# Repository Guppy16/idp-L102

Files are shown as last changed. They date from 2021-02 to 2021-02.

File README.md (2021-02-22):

# IDP L102
Team Name: Root g \
Robots: pi, e

The ultimate repo for the idp

## Task
Design and simulate 2 similar robots with the same controller to collect coloured blocks in an arena.

## Assumptions

Sensor Modules:
- Colour sensor: 1 pixel camera; range of 1 - 10 cm
- Ultrasound sensor: Distance sensor; range = 20 - 140 cm; 3 cm resolution; 5% std
- IR sensor: Same as ultrasound
- Position sensor: GPS sensor; 1 cm accuracy; 3cm resolution
- Rotation sensor: Compass sensor; 5cm resolution

---
## Quick Links
- [Webots Tutorials](https://cyberbotics.com/doc/guide/tutorials)
- [Parts list](https://www.vle.cam.ac.uk/pluginfile.php/19716321/mod_resource/content/0/Tools%20and%20Parts%20List%20Rev%202.0.pdf)
- [CAD Model](https://drive.google.com/drive/folders/1H2YYnImyA4o20oNFYkEqHbo80u9imQ9U?usp=sharing)
- [G Drive Folder](https://drive.google.com/drive/folders/1ipIikCvn5a5h6eHkmM2m4k-qFC2ZiWPo)

---
## Schedule
- Week 1
  - Tue 26 14:30 - [First Presentation](https://docs.google.com/presentation/d/1Jz8pw5dtujUt2GG7nFzDspJj2hsbr5QpLF5pbWbA2lo)
- Week 2
  - Thurs 28 16:00 - [First Report](https://docs.google.com/presentation/d/1Jz8pw5dtujUt2GG7nFzDspJj2hsbr5QpLF5pbWbA2lo)
  - Tue 2 14:30 - [Progress Meeting 1](https://docs.google.com/presentation/d/1rXteifI9VppYjKGW0S_Uu-YhoCQ_Fu2L5HWq04Rq7eM)
- Week 3
  - Tue 9 14:30 - [Progress Meeting 2](https://docs.google.com/presentation/d/10YraGNGObi2IVQ-5OzObUJLeiZdhKT9rYpSfk6eRZUg)
- Week 4
  - Thurs 11 09:00 - First Competition
  - Tue 16 09:00 - [Final Presentation](https://docs.google.com/presentation/d/1EIgQiFh6fY0tn3hVZZiFkF7x_DoJgEBwd8sGT5k-Sp4)
  - Wed 17 14:00 - Final Competition
- Week 5
  - Mon 22 16:00 - Final Report and Documentation Deadline

## Plan
- [Gannt Chart](https://docs.google.com/spreadsheets/d/1-Yt5QpvAf2re6IKUbvELp7eMGsR5QatMflTM9JjYLDc)

- Before the first Presenetation ~ 5 days
  - [x] Gannt chart -> [ ] Make this better
  - [x] Get used to Webots ~ 2 days
  - [x] Initial CAD and PCB design ~ 5
  - [x] Inital algorithms for navigation ~ 4
- Before progress Meeting 1 ~ 7 days
  - [x] Complete simulation of environment (2 robots)
  - [x] Complete cad design of bulk components ~ 5
  - [x] Finished full schematic ~ 3
  - [x] Started implementing algorithms ~ 3
- Before Progress Meeting 2 ~ 7 days
  - [x] Finished CAD design
  - [x] Implemented Algorithms
  - [x] Start documentation
- Before First Competition ~ 2 days
  - [x] Fully tested algorithms in simulation
- Before Final Presentation
  - [x] Complete presentation ~ 
- Before Final Competition
  - [x] Improved the simulation environment
  - [x] Improved algorithms
- Before Final Report
  - [x] Mechanics Docs
  - [x] Electrical Docs
  - [x] Software Docs
  - [x] Cleanup README file

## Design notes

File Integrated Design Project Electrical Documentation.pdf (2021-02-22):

## Integrated Design Project Electrical Documentation

IDP Group L102

Downing College

Team: root g

Robots: e, π

Name | Lab Group
Cameron Spiers | 120
Haymandhra Pillai | 120
Akash Gupta | 124
Noah Gordon | 124
Pengyu Zhang | 125
Tommy Rochussen | 126
Assessor | Prof Tim W.
Tech Advisor | Caglar K.

## Modules in use

Module | Purpose / Components
Arduino | Micro controller - bridge between software and hardware
Motor Shield | Bridge between motors and Arduino
1308 Motor | High rpm motor to drive wheels
Servo Motor | Control orientation of distance sensor for mapping
LED indicators | Indicate which part of the code is being executed
Colour Sensor | LEDs + Colour Filter + LDR & Phototransistor Detect colours (red & blue)
Distance Sensor | Ultrasonic Distance Sensor – detect walls IR Distance Sensor -detect blocks

Table 1. List of modules and their components

## Protoboard

Parts List

Part Number | Value | Notes
R1, R5 | 10kΩ | Set a potential divider together with LDR / Phototransistor
R2, R3, R4, R6 | 150Ω | Value calculated below
J1 | - | Header Right Angle 4-Pole to connect Ultrasonic Distance Sensor
J2 | - | Header Right Angle 3-Pole to connect IR distance sensor
T1 | SFH 313A | IR NPN Phototransistor
T2 | NSL 5112 | LDR
LED1, LED4 | - | LED 3mm Red / Blue (depends on the colour of the robot)
LED2 | - | LED 3mm Blue used as indicator
LED3 | - | LED 3mm Red used as indicator
Sensor | - | IR Distance Sensor GP2Y0A02YK0F 150cm
Sensor | - | Ultrasonic Distance Sensor

Table 2. Parts list for the protoboard

Calculations:

R2 = R3= … = R7 =

Vcc−VLED
I

=

5−2
20 × 10⁻³ = 150 Ω

Circuit Diagram:

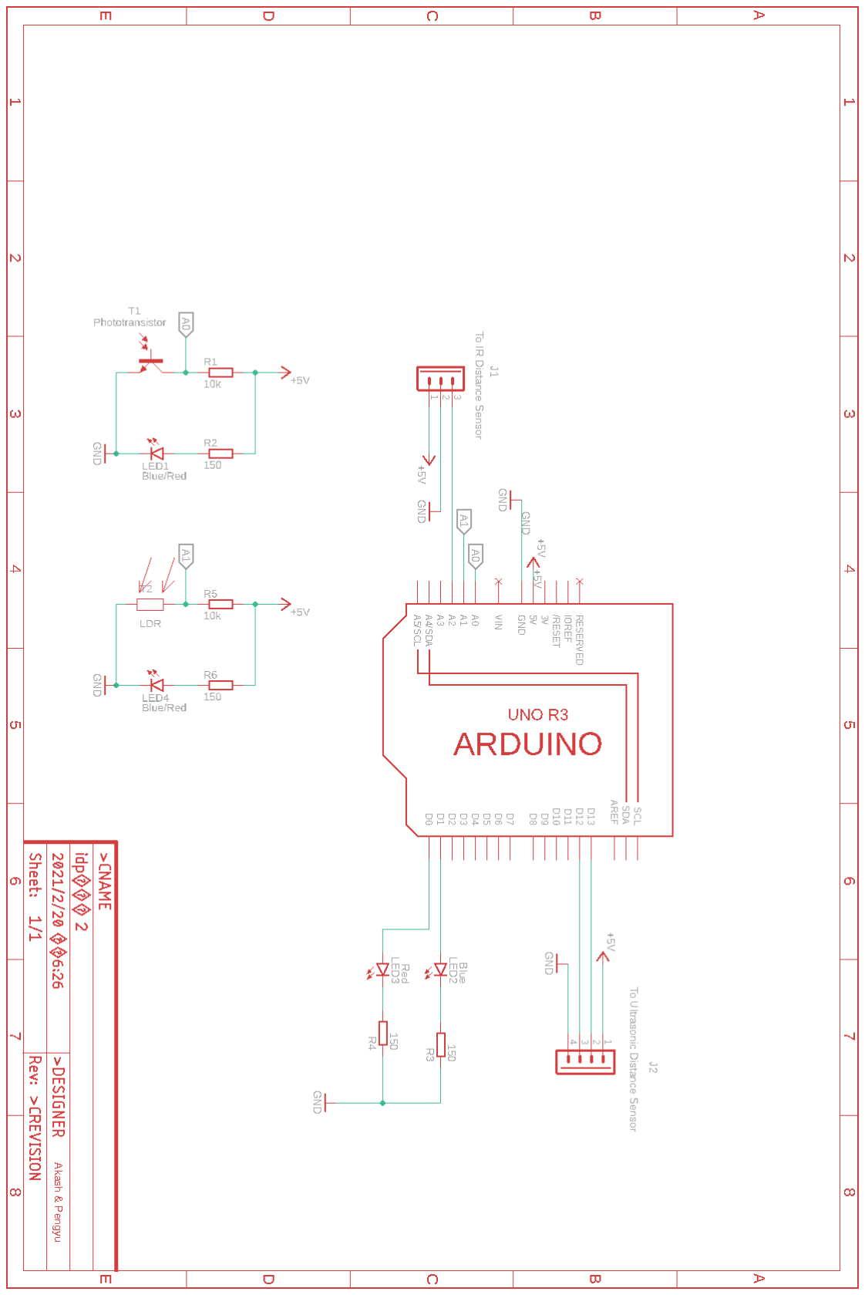
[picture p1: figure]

Figure 1. Circuit Diagram

Board Layout:

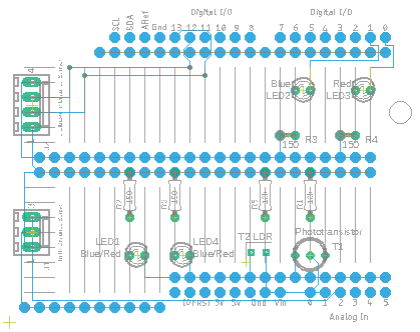
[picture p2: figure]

Figure 2. Connections of the layout of the circuit board

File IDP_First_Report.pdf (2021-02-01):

# IDP First Report

Team: root g
Robots: e, π

IDP Group L102

January 27, 12021

Downing College

Name | Lab Group
Cameron Spiers | 120
Haymandhra Pillai | 120
Akash Gupta | 124
Noah Gordon | 124
Pengyu Zhang | 125
Tommy Rochuseen | 126
Assessor | Prof Tim W.
Tech Advisor Caglar K.

## 1 Task

### 1.1 Task Brief

- Design a robot and control algorithm to pick up coloured blocks and deliver them home
- Ensure that the robot doesn’t collide with the other one
- Simulate the robot in Webots

### 1.2 Our Approach

We have decomposed the problem into 4 critical areas and who will be working on them:

1. Mechanical - Cameron & Haymandhra
2. Electrical - Akash & Pengyu
3. Software - Noah & Tommy
4. Simulation - Everyone

Our approach consists of tackling the first 3 parts in parallel before combining them together. However, we are aware that the biggest mistake is to not perform any integration testing, hence we plan to take an iterative approach, where we frequently test our ideas and models together in the simulated environment and go back to the drawing board to improve our design. Also, since the controller will be developed much later on, we have made a simple arrow key based simulation for the mechanical side to test their design.

### 1.3 Potential challenges

- Preventing collision with the other robot
- Ensuring the block is head on when picking it up
- Collecting blocks on the edges/corners
- Ensuring everything works together

We believe that best way to mitigate any delays in solving these problems will be to continually test what we have and rapidly prototype designs and controllers, which is reflected in our approach and Gannt chart.

## 2 System

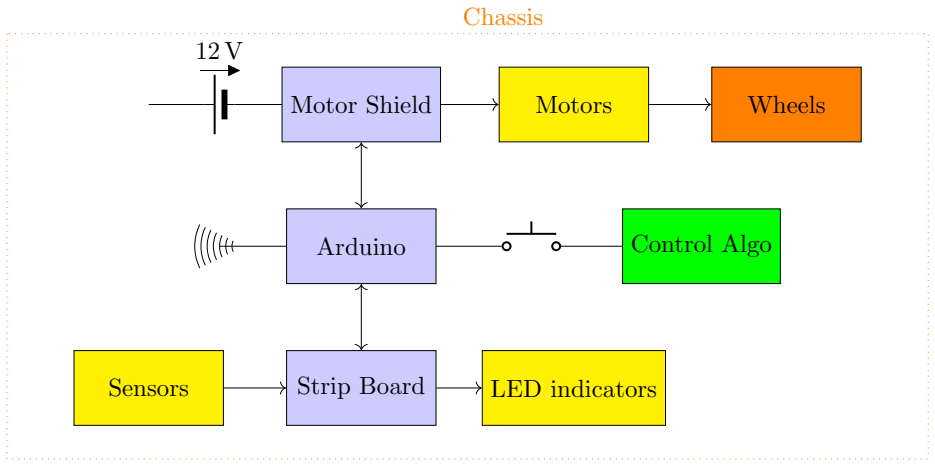
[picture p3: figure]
Motor Shield; Motors; Wheels; Arduino; Control Algo; Sensors; Strip Board; LED indicators; Chassis

Computer
with map

## 3 Robot Concept

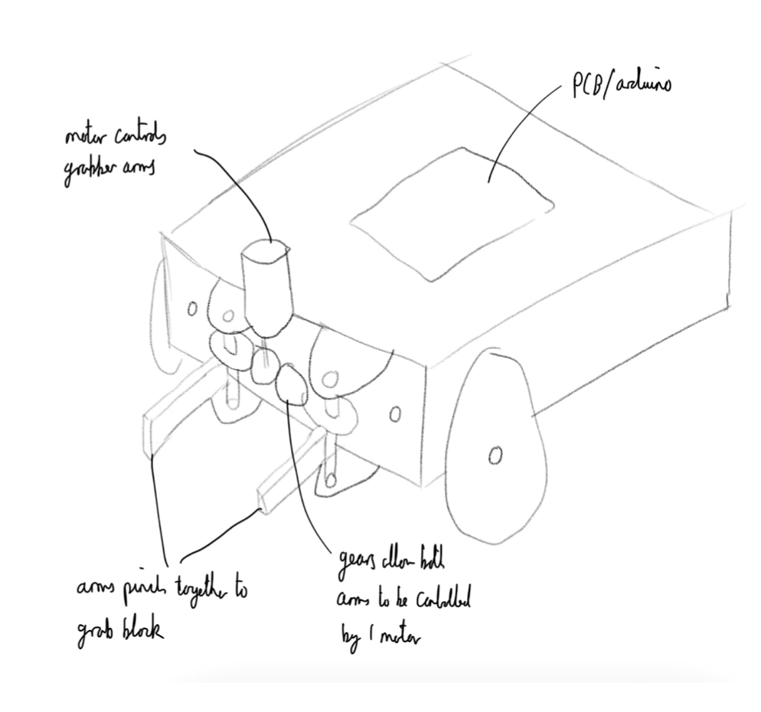
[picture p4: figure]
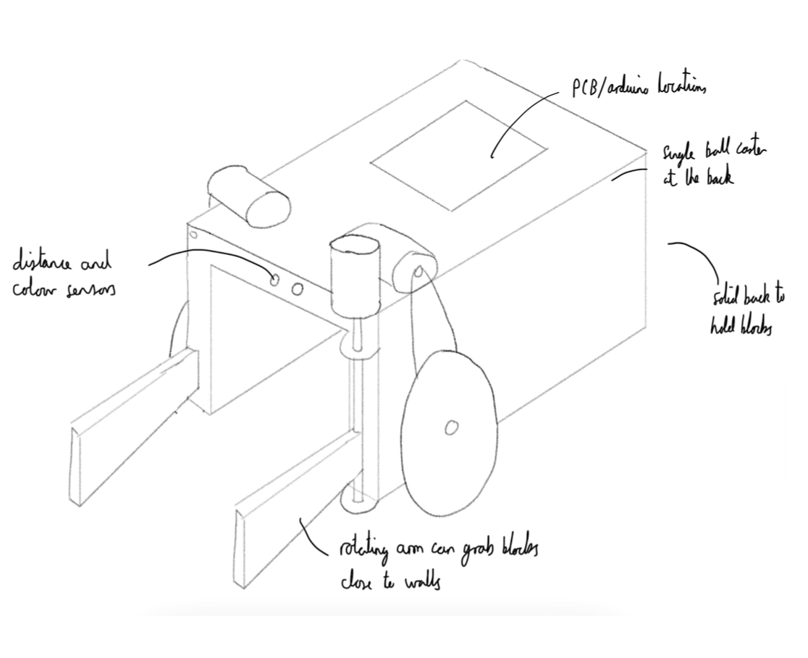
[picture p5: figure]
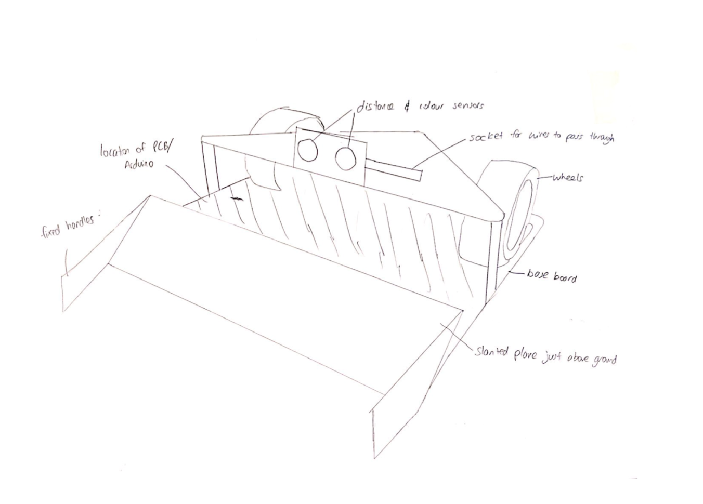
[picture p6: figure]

(a) Collector | (b) Scraper | (c) Picker

Figure 1: Initial sketches

Bot Name | Advantages | Disadvantages
Collector | Simply has to drive over blocks Can collect and transport multiple blocks | Handling is more difficult, and increased friction Complex pulley-belt mechanism for wheels
Scraper | Able to access blocks along corners and edges Lighter, hence a smaller motor Can guide multiple blocks | Blocks might not be safely guided to their destination Could slip while picking up blocks Wheel at the back due to the front bucket
Picker | Can easily grab blocks in any location The main body of the robot is very simple Less likely to slip | Complex gear and hing assembly to grab blocks Can only collect one block at a time Dragging blocks reduces handling

Table 1: Table evaluating the initial sketches

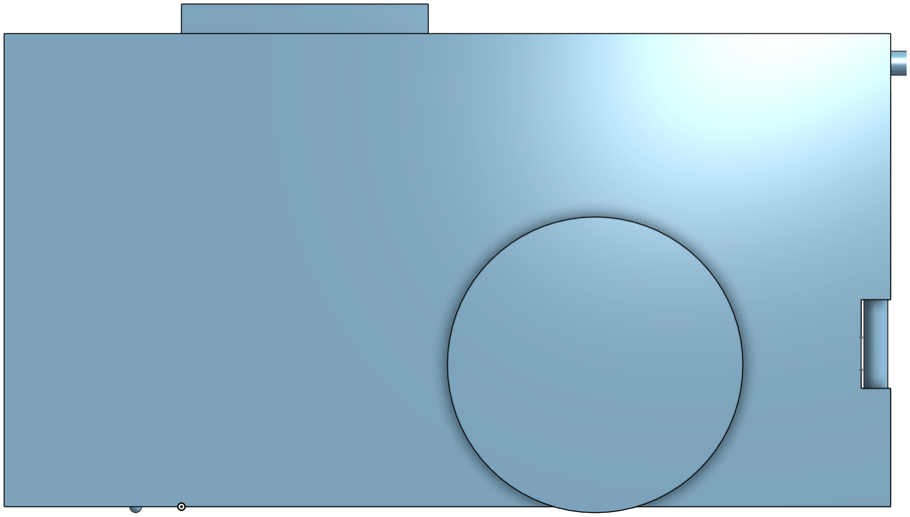
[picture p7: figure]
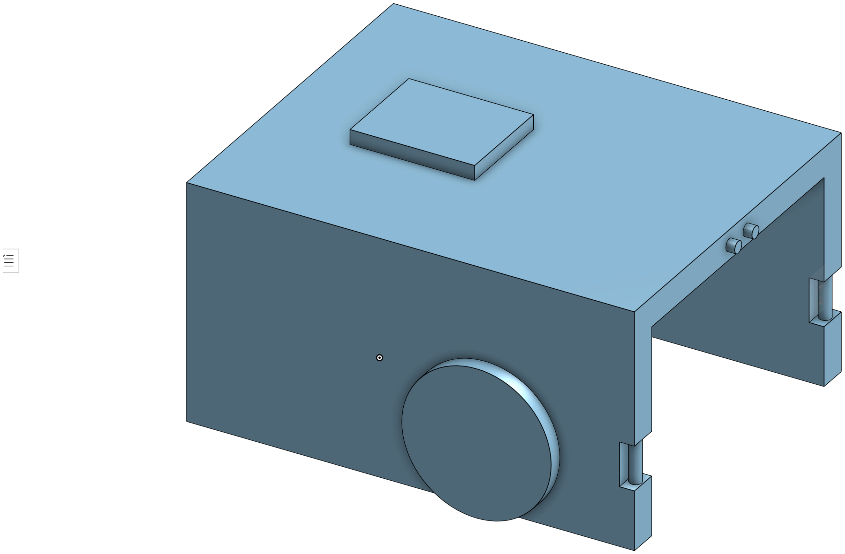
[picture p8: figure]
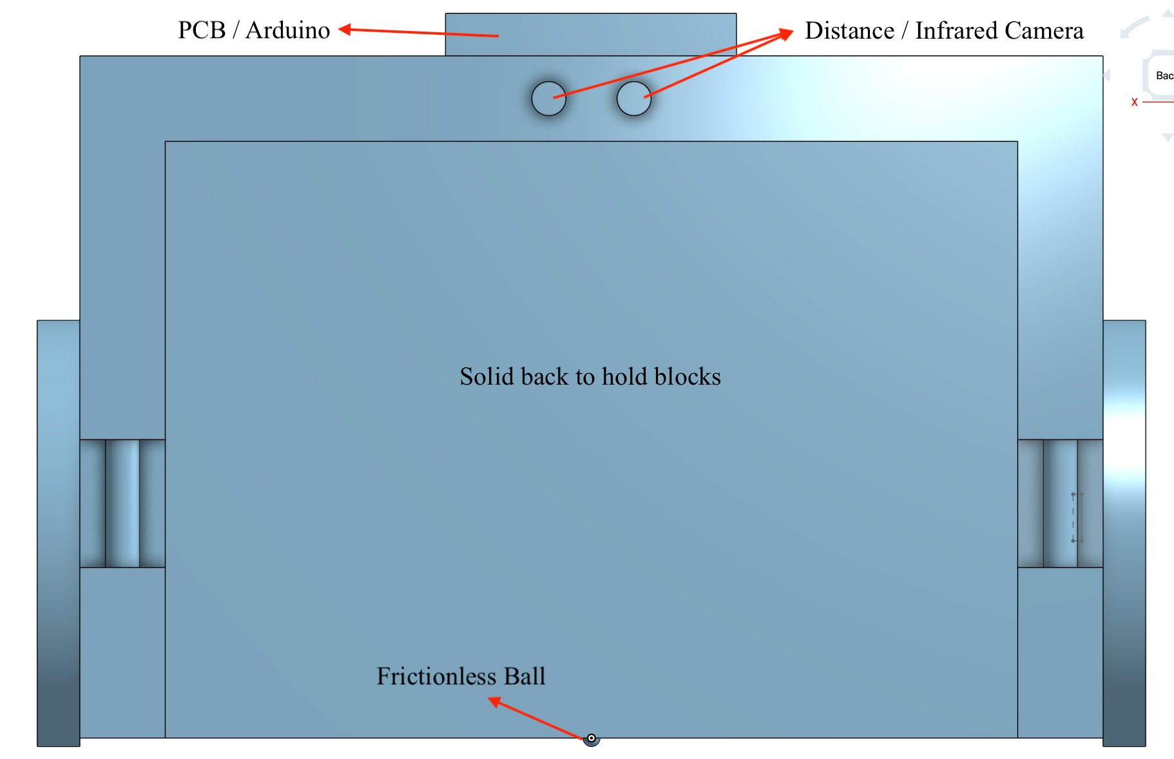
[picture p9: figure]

(a) Front | (b) Side | (c) Isometric

Figure 2: Simplified CAD model of Collector

Based on our evaluation of the initial sketches, we decided to design the Collector due to its simplicity and versatility. Once we test this design in the simulation, we will either improve this or pick one of our other designs. Also note that the design will be improved later on to consider the size of the electronic components.

## 4 Electronics and Sensing

Module | Purpose
Arduino | Micro controller - bridge between software and hardware
LEDs + Colour Filter + LDR | Colour Sensor
Ultrasonic Distance Sensor | Precise and high range distance measurement
Servo Motor | Control orientation of distance sensor for mapping
Hall Effect (Magnet) Sensor | Orientation Sensor
LED indicators | Indicate which part of the code is being executed
Motor Shield | Bridge between motors and Arduino
1308 Motor | High rpm motor to drive wheels

Table 2: Preliminary list of modules and their components.

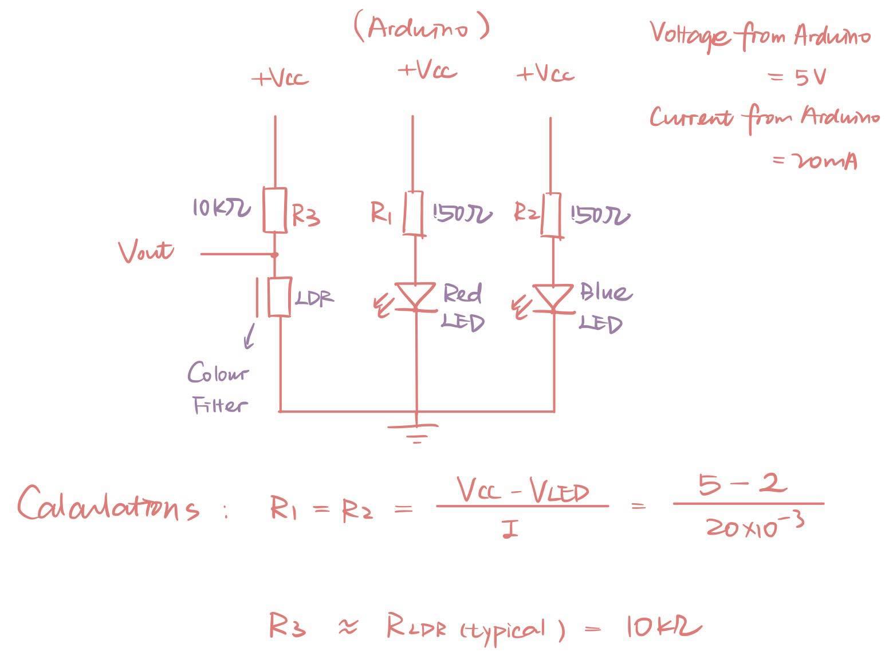
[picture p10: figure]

Figure 3: Schematic for colour sensor with calculations

The sensors produce an analogue signal, which will be read by the Arduino through an analogue input pin, which will be converted to a digital signal via an internal DAC. These will be fed into our controller to decide the next action. Notably, the range of output voltages for the sensors vary, hence this will need to be considered (e.g. through calibration) in the code.

## 5 Controller

This is arguably the most complicated part due to the constraints of simulation vs reality. The software will take inputs from sensors and use these to control the actuators and motors. LED indicators will be used for debugging purposes. We aim to mitigate the differences by designing and testing algorithms to cope for real life uncertainties and random errors. The algorithm is outlined as follows:
while not all the blocks have been collected do
scan the arena for the other robot
if the other robot is nearby then
Move away
end
scan the arena for objects
if a block is found then
get closer to the block
check the colour of the block
if the block is the correct colour then
pick it up
if the block has been picked up successfully then navigate back home
else
try again
end
keep track of the blocks collected else
mark this as not my block
end
end
if a wall is found then
turn right
end
Keep moving forward
end
Algorithm 1: Core algorithm of controller

There are simple pitfalls in this algorithm:

- How do we tell if the other robot is nearby
- How do we distinguish a wall from a block
- How do we tell if we’re aligned with the block
- How do we tell if the block has been picked up
- How do we navigate the robot around

Some of these can be solved with software and some with the help of hardware. Algorithms for each of these questions will need to be implemented, but more detail can only be given after testing the pitfalls in the Webots simulation. Possible solutions are listed below:

- Construct a simple map of the block positions and robots, which can be updated by each robot
- Add a light sensor / push sensor to detect a block
- Navigation algorithms include A* or Dijkstra’s, which require a map. Instead a simple snake search might be easier.

## 6 Timeline

# IDP GANTT CHART

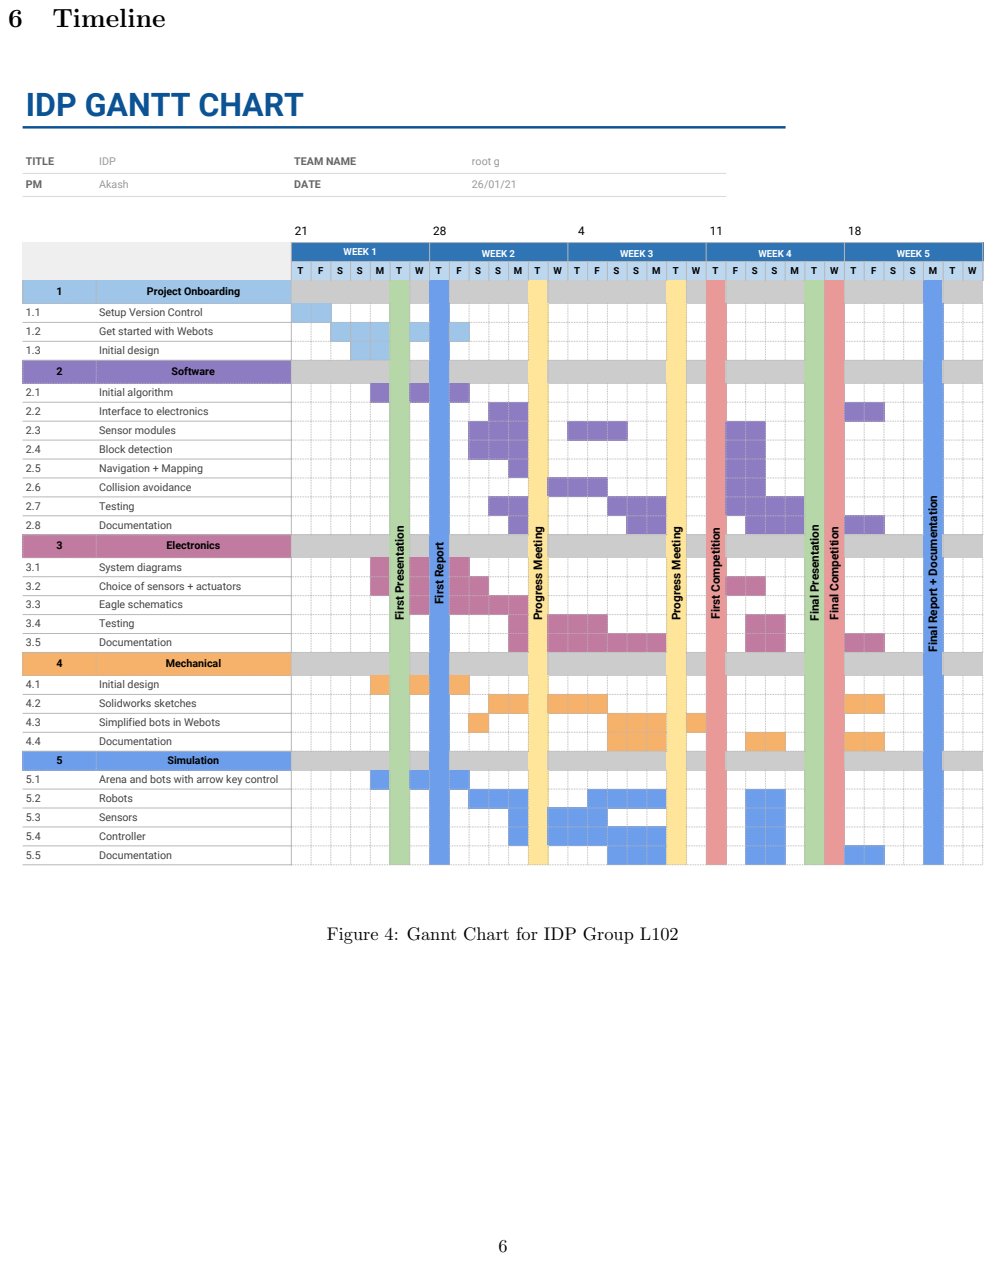
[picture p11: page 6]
TITLE; IDP; TEAM NAME; root g; Akash; DATE; WEEK 1; WEEK 2; WEEK 3; WEEK 4; WEEK 5; 1 Project Onboarding; First Presentation; First Report; Progress Meeting; First Competition; Final Presentation; Final Competition; Setup Version Control; Get started with Webots; Initial design; 2 Software; Initial algorithm; Interface to electronics; Sensor modules; Block detection; Navigation + Mapping; Collision avoidance; Testing; Documentation; 3 Electronics; System diagrams; Choice of sensors + actuators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

Final Report + Documentation

Figure 4: Gannt Chart for IDP Group L102

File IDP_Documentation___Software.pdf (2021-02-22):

# IDP Documentation - Software

Team: root g
Robots: e, π

IDP Group L102

February 22, 12021

Downing College

Name | Lab Group
Cameron Spiers | 120
Haymandhra Pillai | 120
Akash Gupta | 124
Noah Gordon | 124
Pengyu Zhang | 125
Tommy Rochuseen | 126

Assessor Prof Tim W.
Advisor Caglar K.

Link to Repository: https://github.com/Guppy16/idp-L102

## 1 Software Approach

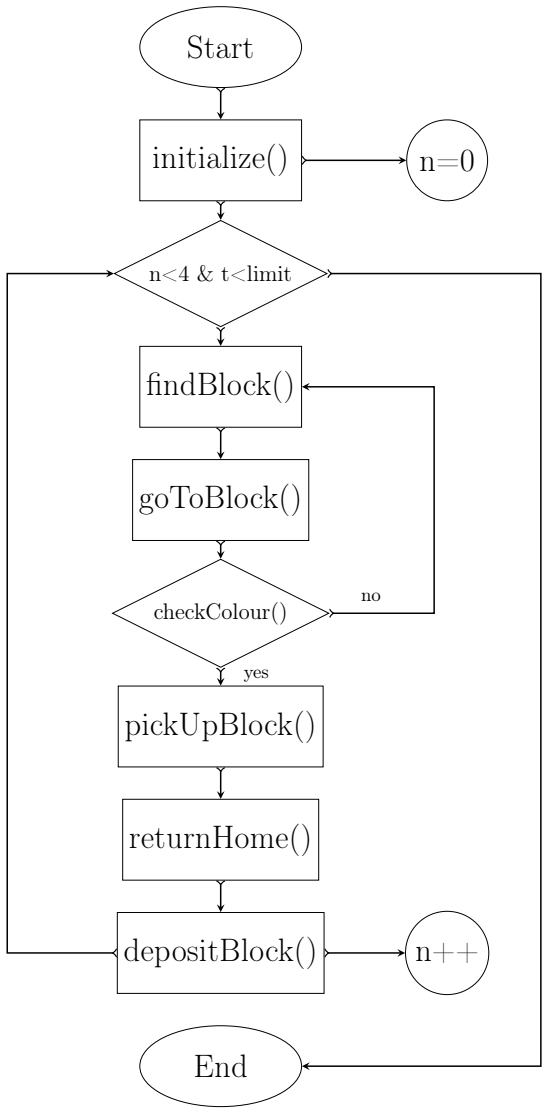
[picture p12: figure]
Start; initialize(); n<4 & t<limit; findBlock(); goToBlock(); checkColour(); pickUpBlock(); returnHome(); depositBlock(); End; yes

Figure 1: Flow chart showing the top level functions used in one control loop. The timer is set to run for 2.5 minutes, so that each robot can take it in turn to find a block

## 2 Structure

- Only one controller was used
- Note that one loop in the flowchart doesn’t correspond to one timestep, but the loop breaks after 2 minutes to allow the robot to return home
- A file was kept to store the initial position of the robots and threshold values for the colour sensor
- Our approach was to split the code into 3 main modules: Robocar class, Controller module, Utility functions

### 2.1 Robocar Class

The robocar class extends the robot class provided in Webots. Robocar is designed to initialises the sensors and flags, and provides handy functions for sensing and movement.

- init - initialise flags, sensors and actuators
- Sensor functions: update sensors, getHeadingDegrees, get ds sensor object pos, detect block colour
- Driving functions: go forward, go backwards, turn left, turn right, turn and drive, stop, rotate
- Integrated functions: rotate to bearing, return home, get other robot pos

### 2.2 Controller Module

- find blocks
- rotate to target block
- check block colour
- drive around block
- check front clear
- go

### 2.3 Utility Functions

- next block - finds the closest block in a list, which hasn’t been picked up
- ds sensor to m - converts the distance sensor value to a distance using linear interpolation from a lookup table
- is within range - checks if two position vectors are close to each other
- getLocationBearing
- bearing to vec

## 3 Core Algorithms

def find blocks()
while current heading - original heading < 360 do Rotate for one timestep
update sensors()
if object detected then
check if it’s a block or a wall
if block detected then
double check in case of error
if NOT close to (other robot OR home) AND is not within 5cm of another block then add block to list
end
end
end
end
if Block list isn’t empty then Target Block ← closest block end

def drive around block()
# Set rotation direction towards the centre of the arena by checking the sign of the cross product if pos vector × heading vector > 0 then

rotate 45o CW
else
rotate 45o CCW
end
Move 30 cm forward

def go(location, range=0.2)
while NOT is within range(pos, location, range) do rotate to location(location)
if NOT frontClear() then
drive around block()
else
go forward()
Update timestep
end
end

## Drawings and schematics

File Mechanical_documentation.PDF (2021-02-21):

# Virtual Integrated Design Project

# Mechanical documentation: L102, Team Root g

# Material choice - 6mm plywood

# Manufacturing techniques - The majority of the robot is laser cut from the 6mm plywood - Some additional holes will need to be drilled and tapped - The plywood will then be glued together using wood glue

- The arduino, battery box and IR sensor are attached to the robot using nuts and bolts and washers where appropriate

# Material justification - The main goal of our design process was to create a simple and reliable robot

- This is why we went for the cheap and easy to handle plywood as an alternative to sheet metal

# - The parts can all be very easily and quickly laser cut out of a single sheet of plywood

- The use of comb joints ensures strength and makes the assembly process fast as pieces slot together only in their correct positions
- We are using 6mm plywood as it is the thickest available and will help make the robot more robust
- The use predominantly of wood also reduces the environmental impact of our robot as it is a sustainable resource

What follows are technical drawings for all of the laser cut parts along with an overall assembly drawing. At the very end is a template with all the parts in their required quantities on a 300mm x 600mm sheet, the same size as the plywood available to us. This is the template that would be used to laser

# cut the parts

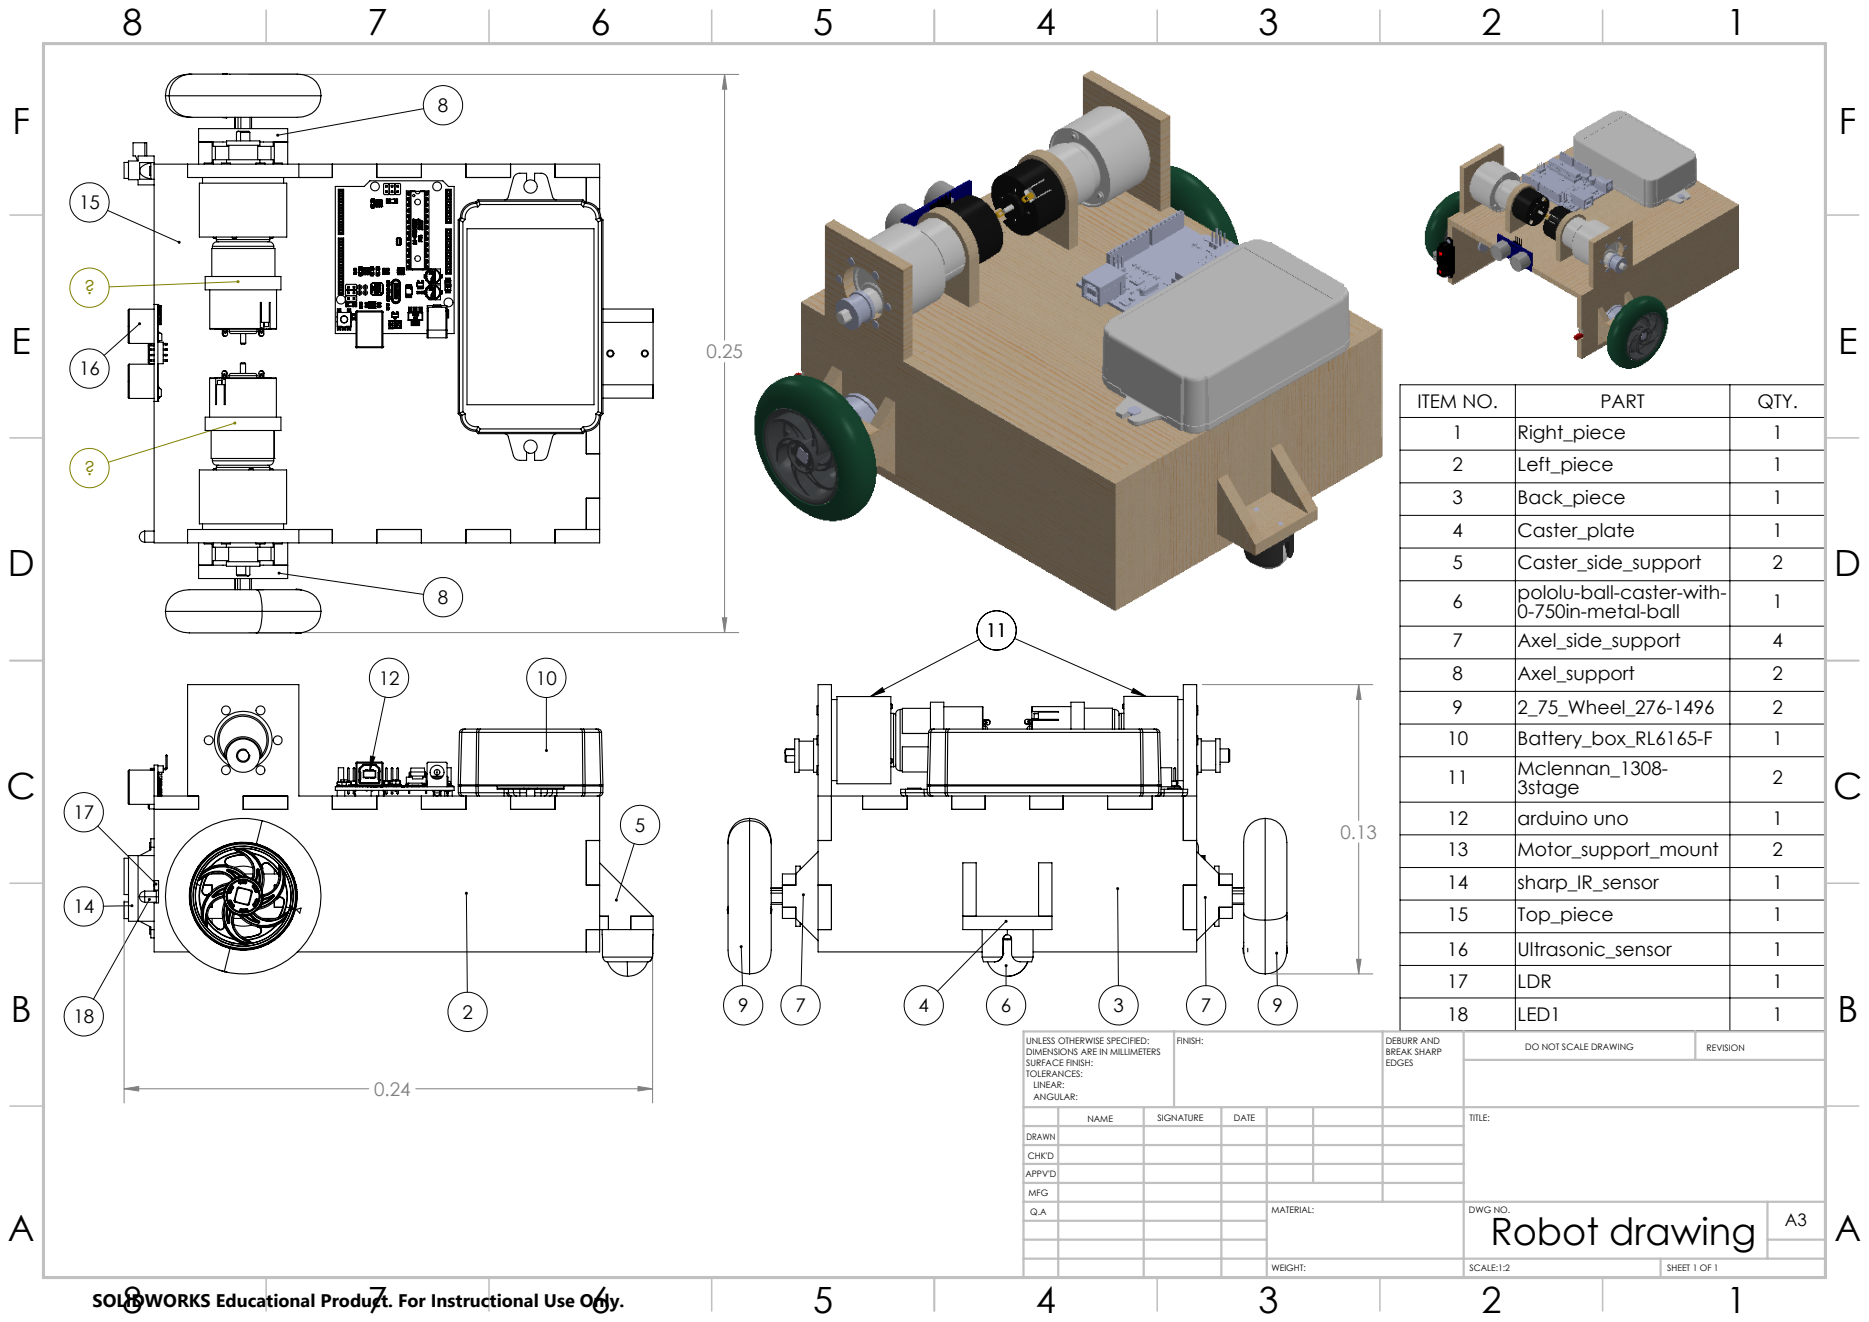
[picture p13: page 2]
SCALE:1:2; SHEET 1 OF 1

ITEM NO. | PART | QTY.
1 | Right_piece | 1
2 | Left_piece | 1
3 | Back_piece | 1
4 | Caster_plate | 1
5 | Caster_side_support | 2
6 | pololu-ball-caster-with-0-750in-metal-ball | 1

7 | Axel_side_support | 4
8 | Axel_support | 2
9 | 2_75_Wheel_276-1496 | 2
10 | Battery_box_RL6165-F | 1
11 | Mclennan_1308-3stage | 2

12 | arduino uno | 1
13 | Motor_support_mount | 2
14 | sharp_IR_sensor | 1
15 | Top_piece | 1
16 | Ultrasonic_sensor | 1
17 | LDR | 1
18 | LED1 | 1

UNLESS OTHERWISE SPECIFIED: DIMENSIONS ARE IN MILLIMETERS SURFACE FINISH: TOLERANCES: LINEAR: ANGULAR: | FINISH: | DEBURR AND BREAK SHARP EDGES | DO NOT SCALE DRAWING | REVISION

NAME | SIGNATURE | DATE | | | | TITLE:

DRAWN
CHK'D
APPV'D
MFG
Q.A | | | | MATERIAL: | DWG NO. Robot drawing | A3

SOLIDWORKS Educational Product. For Instructional Use Only.

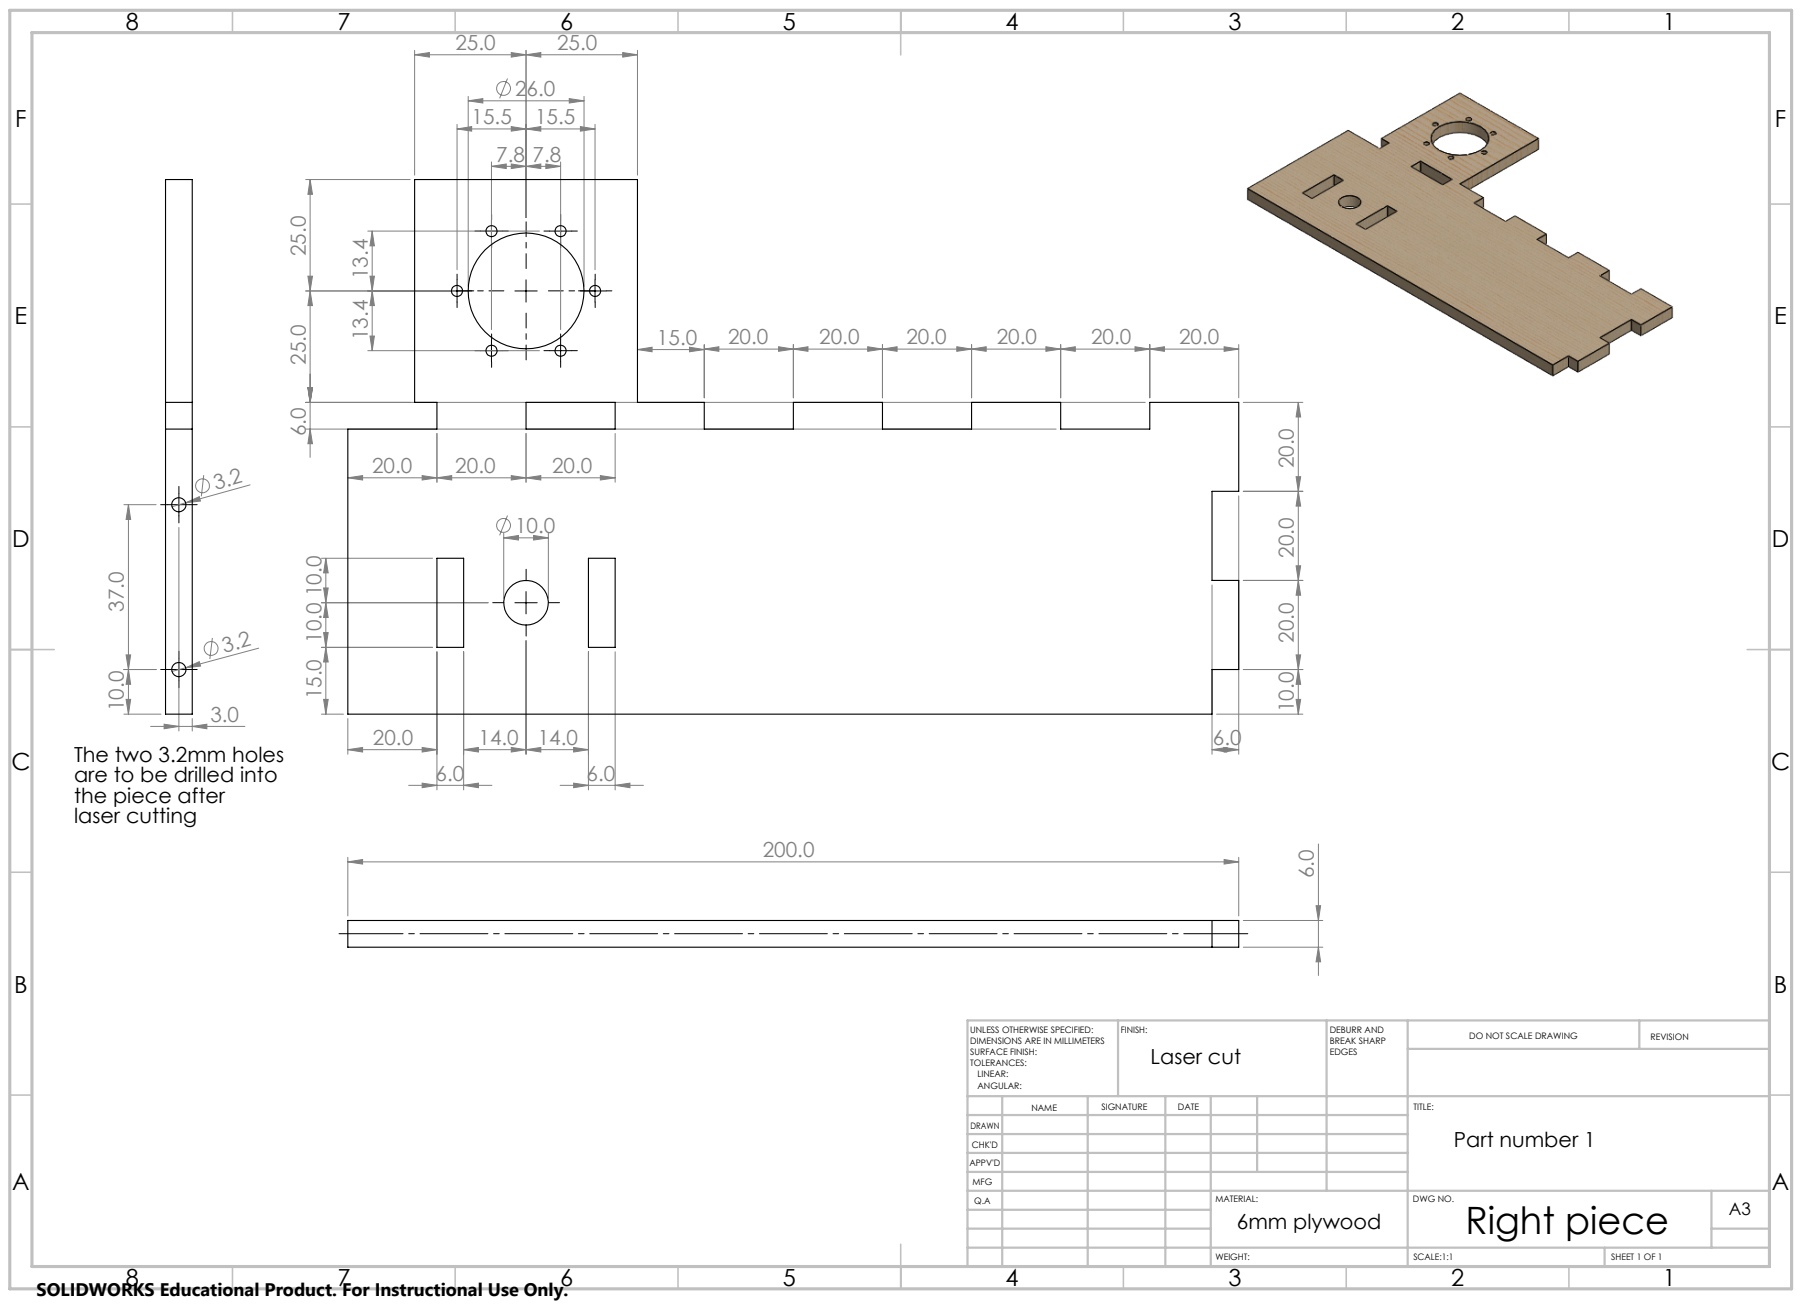
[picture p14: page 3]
Laser cut; FINISH:; DEBURR AND; BREAK SHARP; DO NOT SCALE DRAWING; REVISION

25.0
26.0
15.5 | 15.5
7.8

The two 3.2mm holes
are to be drilled into
the piece after
laser cutting

UNLESS OTHERWISE SPECIFIED:
DIMENSIONS ARE IN MILLIMETERS
SURFACE FINISH:
TOLERANCES:
LINEAR:
ANGULAR:

NAME | SIGNATURE | DATE | | | | TITLE: Part number 1

DRAWN
CHK'D
APPV'D
MFG

6mm plywood | Right piece

SCALE:1:1 | SHEET 1 OF 1

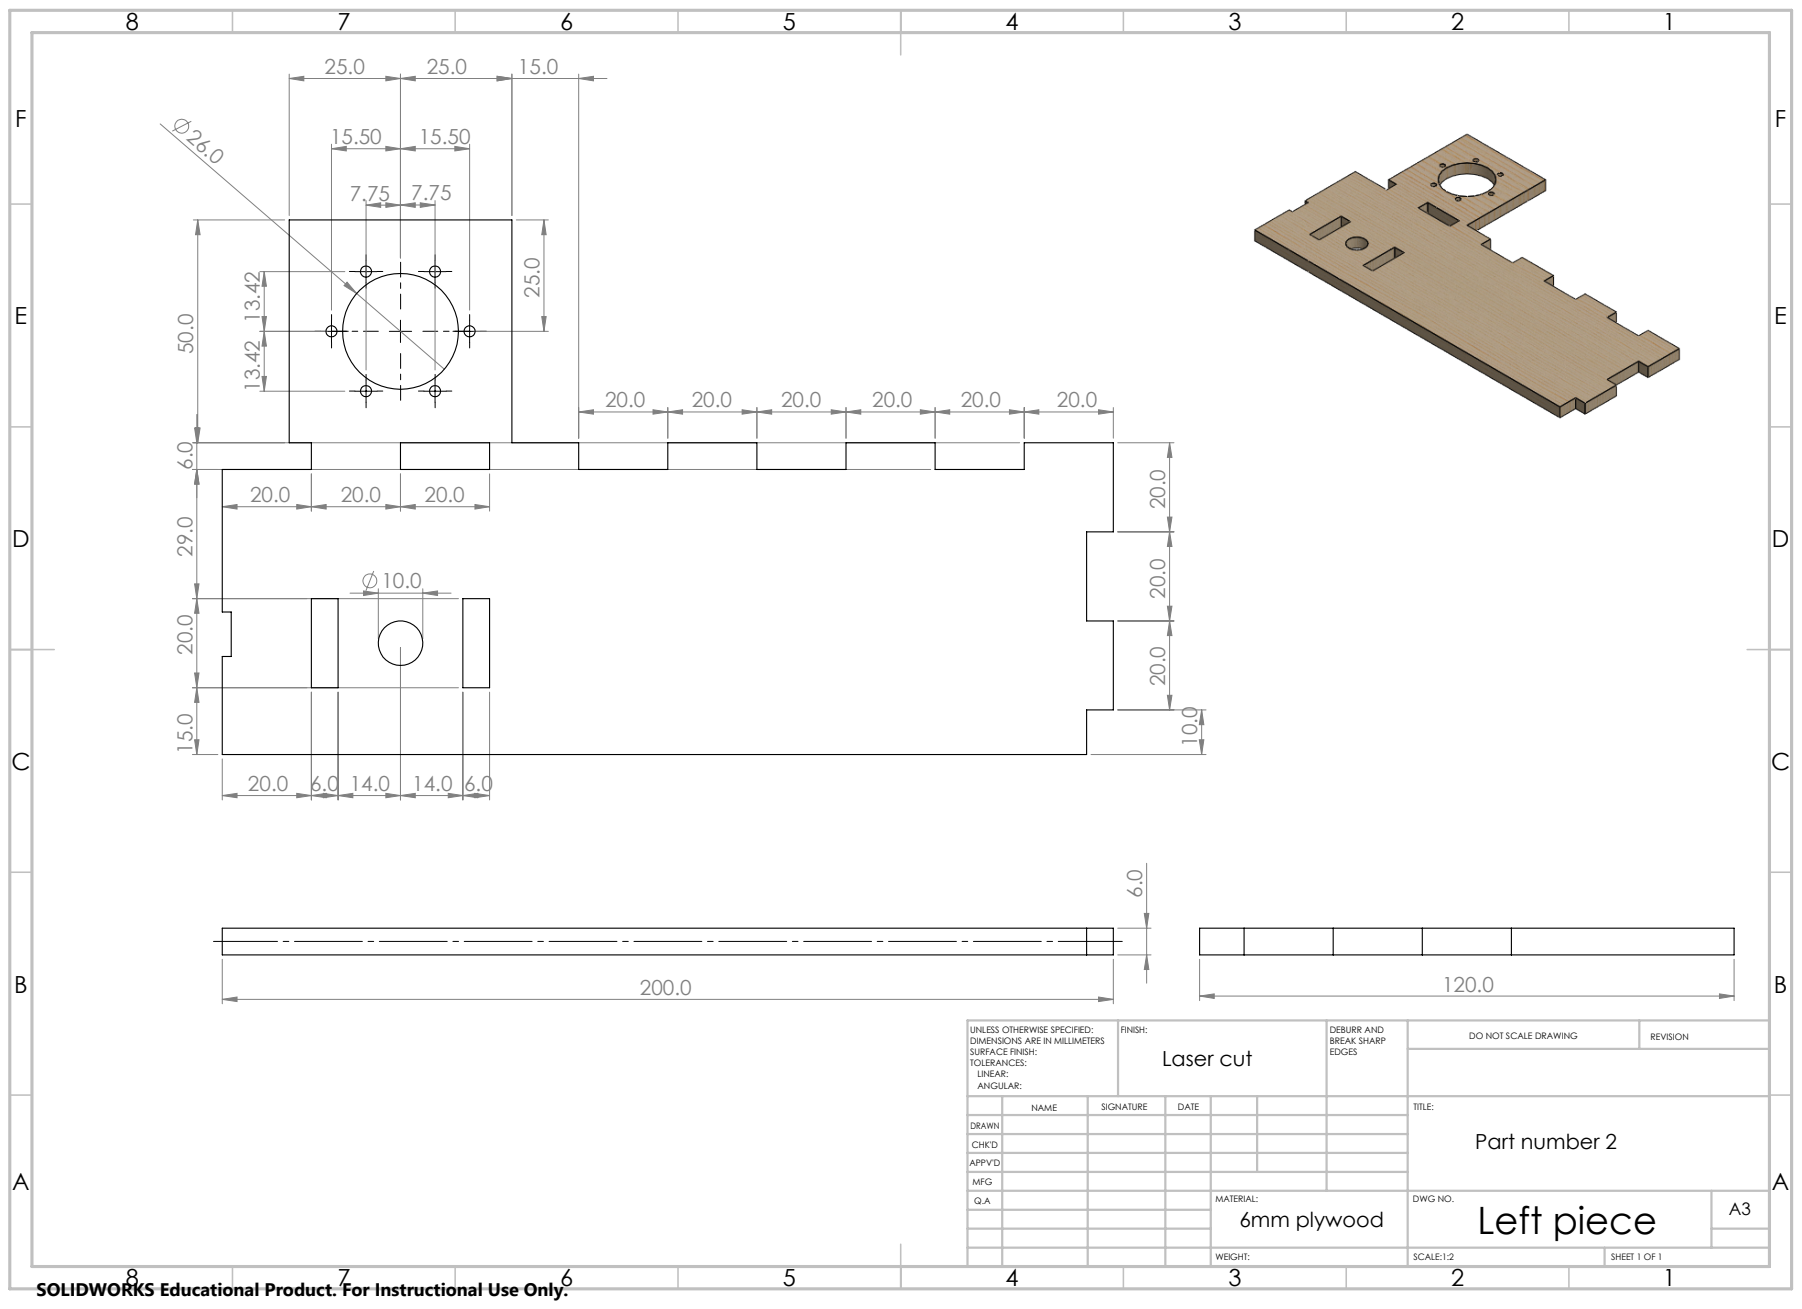
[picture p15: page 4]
Laser cut; FINISH:; DEBURR AND; BREAK SHARP; DO NOT SCALE DRAWING; REVISION

UNLESS OTHERWISE SPECIFIED:
DIMENSIONS ARE IN MILLIMETERS
SURFACE FINISH:
TOLERANCES:
LINEAR:
ANGULAR:

NAME | SIGNATURE | DATE | | | TITLE: Part number 2

DRAWN
CHK'D
APPV'D
MFG

Left piece

SCALE:1:2 | SHEET 1 OF 1

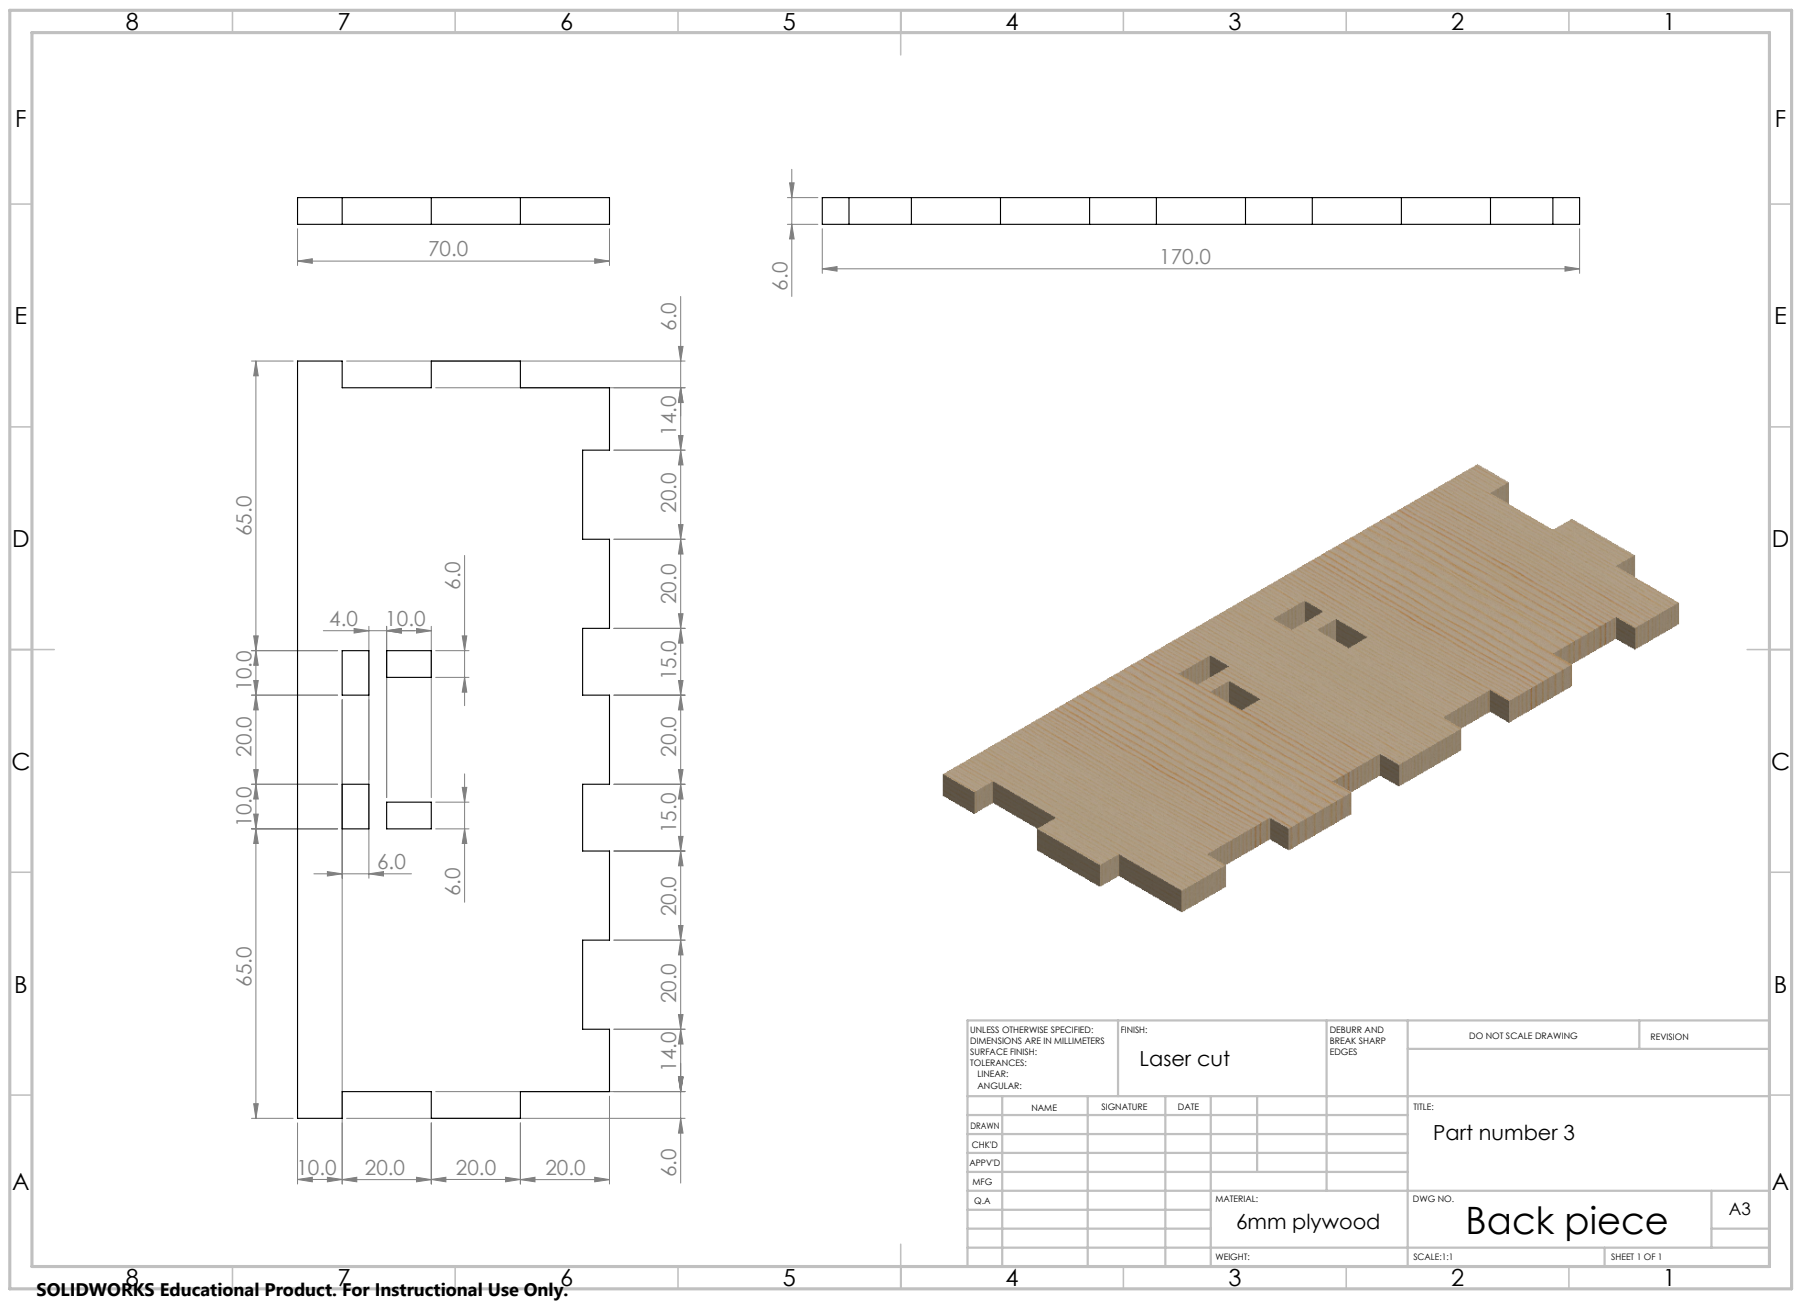
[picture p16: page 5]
Laser cut; FINISH:; DEBURR AND; BREAK SHARP; DO NOT SCALE DRAWING; REVISION

UNLESS OTHERWISE SPECIFIED:
DIMENSIONS ARE IN MILLIMETERS
SURFACE FINISH:
TOLERANCES:
LINEAR:
ANGULAR:

NAME | SIGNATURE | DATE | | | TITLE: Part number 3

DRAWN
CHK'D
APPV'D
MFG

Back piece

SCALE:1:1 | SHEET 1 OF 1

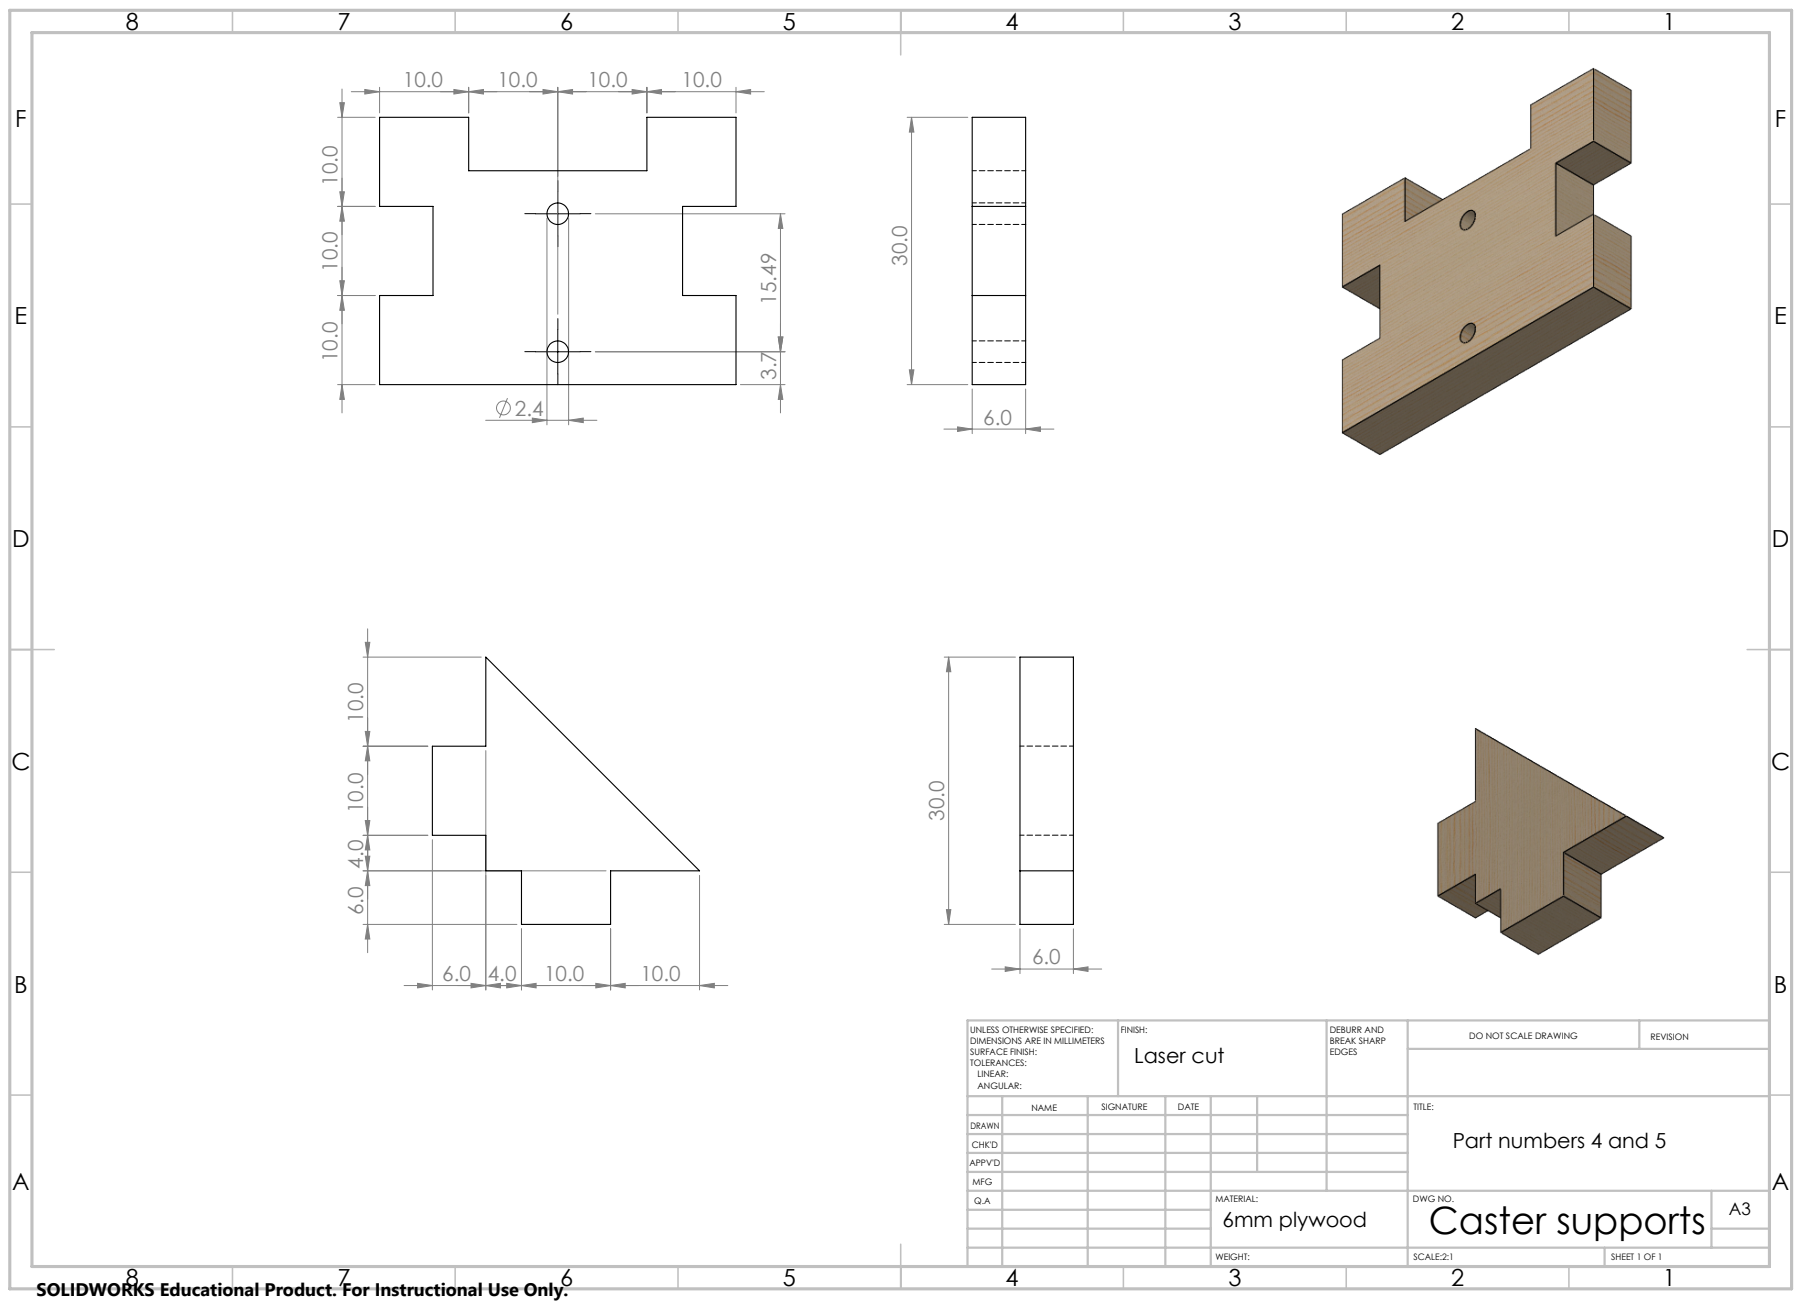
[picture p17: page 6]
Laser cut; FINISH:; DEBURR AND; BREAK SHARP; DO NOT SCALE DRAWING; REVISION

UNLESS OTHERWISE SPECIFIED:
DIMENSIONS ARE IN MILLIMETERS
SURFACE FINISH:
TOLERANCES:
LINEAR:
ANGULAR:

NAME | SIGNATURE | DATE | | | TITLE: Part numbers 4 and 5

DRAWN
CHK'D
APPV'D
MFG

Caster supports

SCALE:2:1 | SHEET 1 OF 1

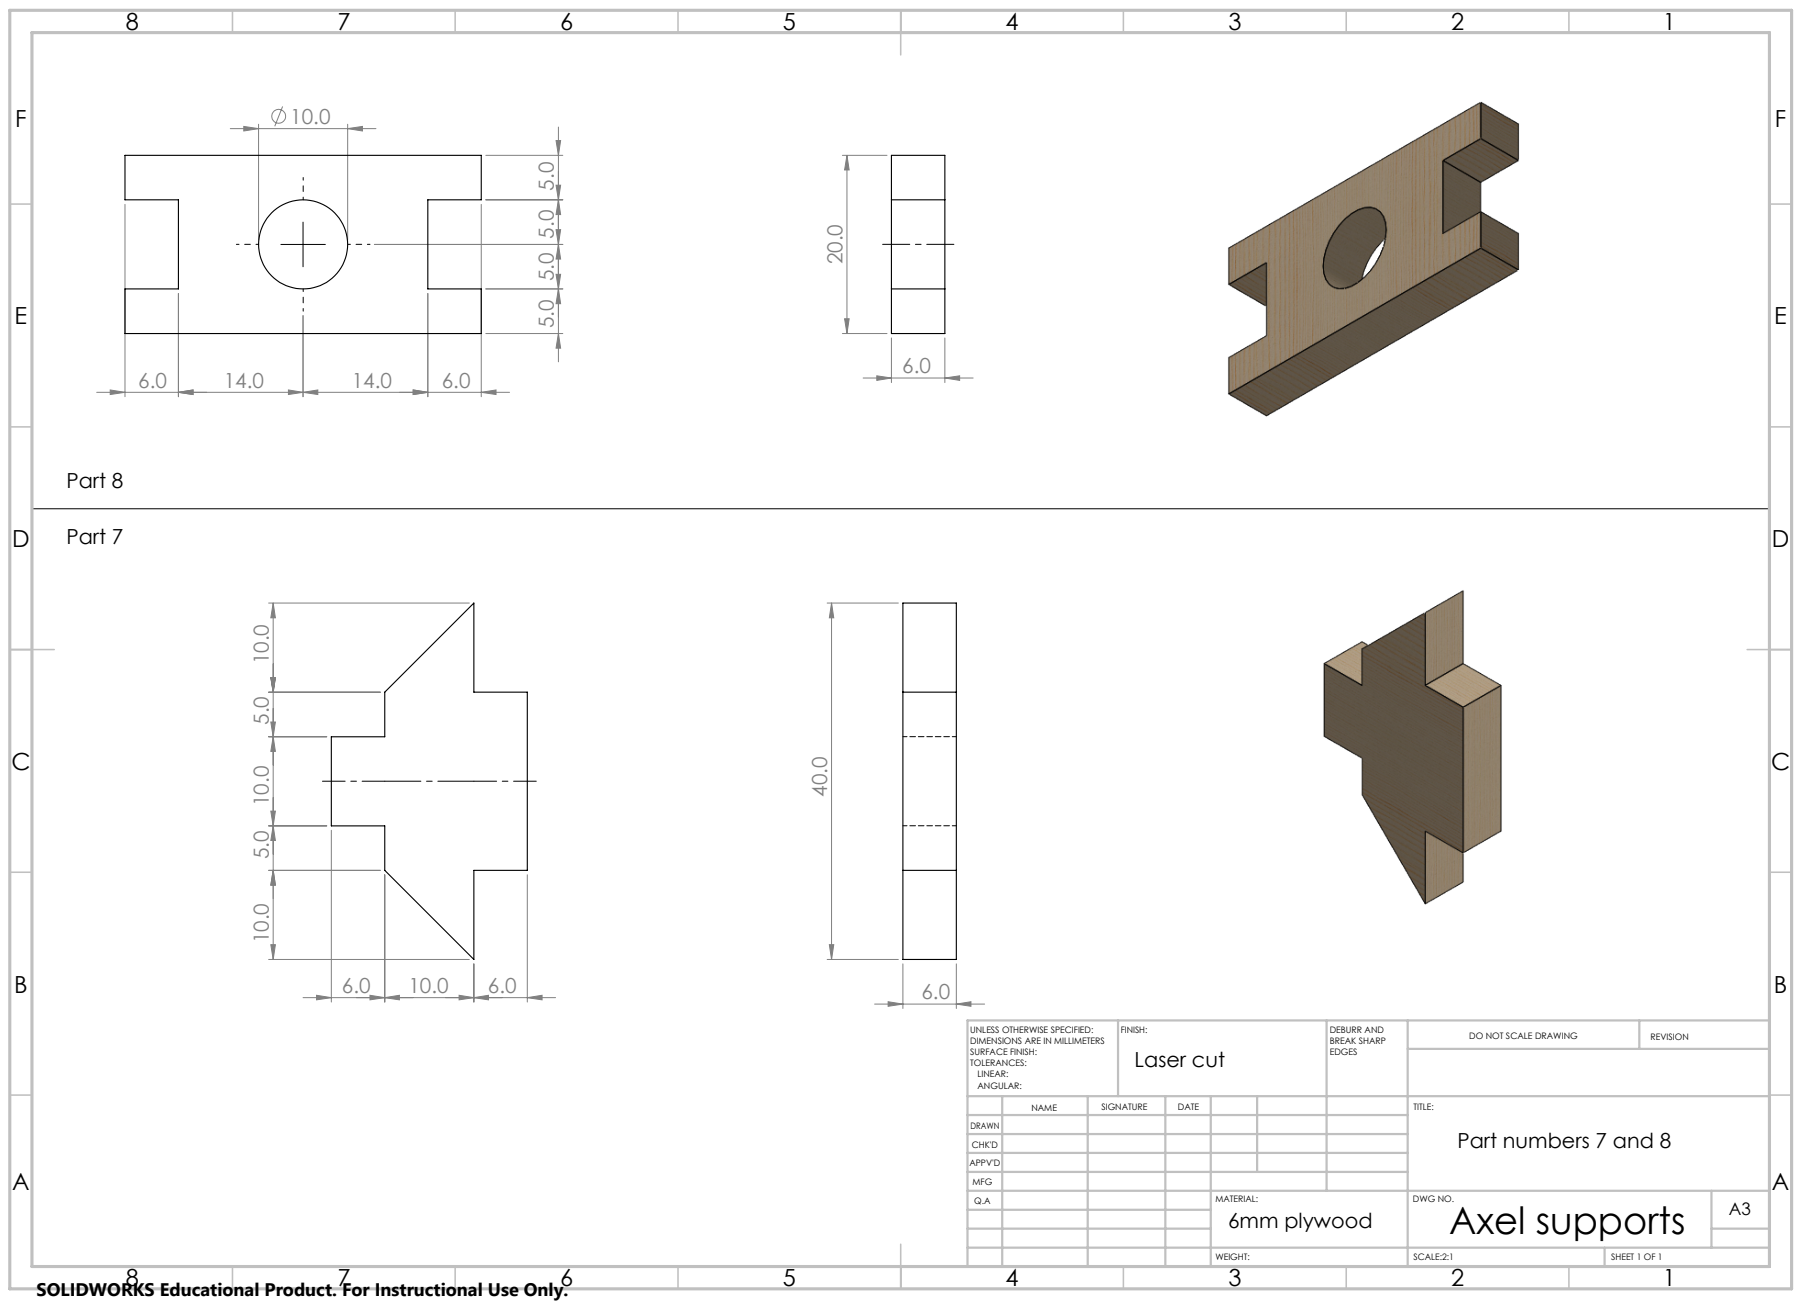
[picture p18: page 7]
Laser cut; Part 8; Part 7; FINISH:; DEBURR AND; BREAK SHARP; DO NOT SCALE DRAWING; REVISION

UNLESS OTHERWISE SPECIFIED:
DIMENSIONS ARE IN MILLIMETERS
SURFACE FINISH:
TOLERANCES:
LINEAR:
ANGULAR:

NAME | SIGNATURE | DATE | | | TITLE: Part numbers 7 and 8

DRAWN
CHK'D
APPV'D
MFG

Axel supports

SCALE:2:1 | SHEET 1 OF 1

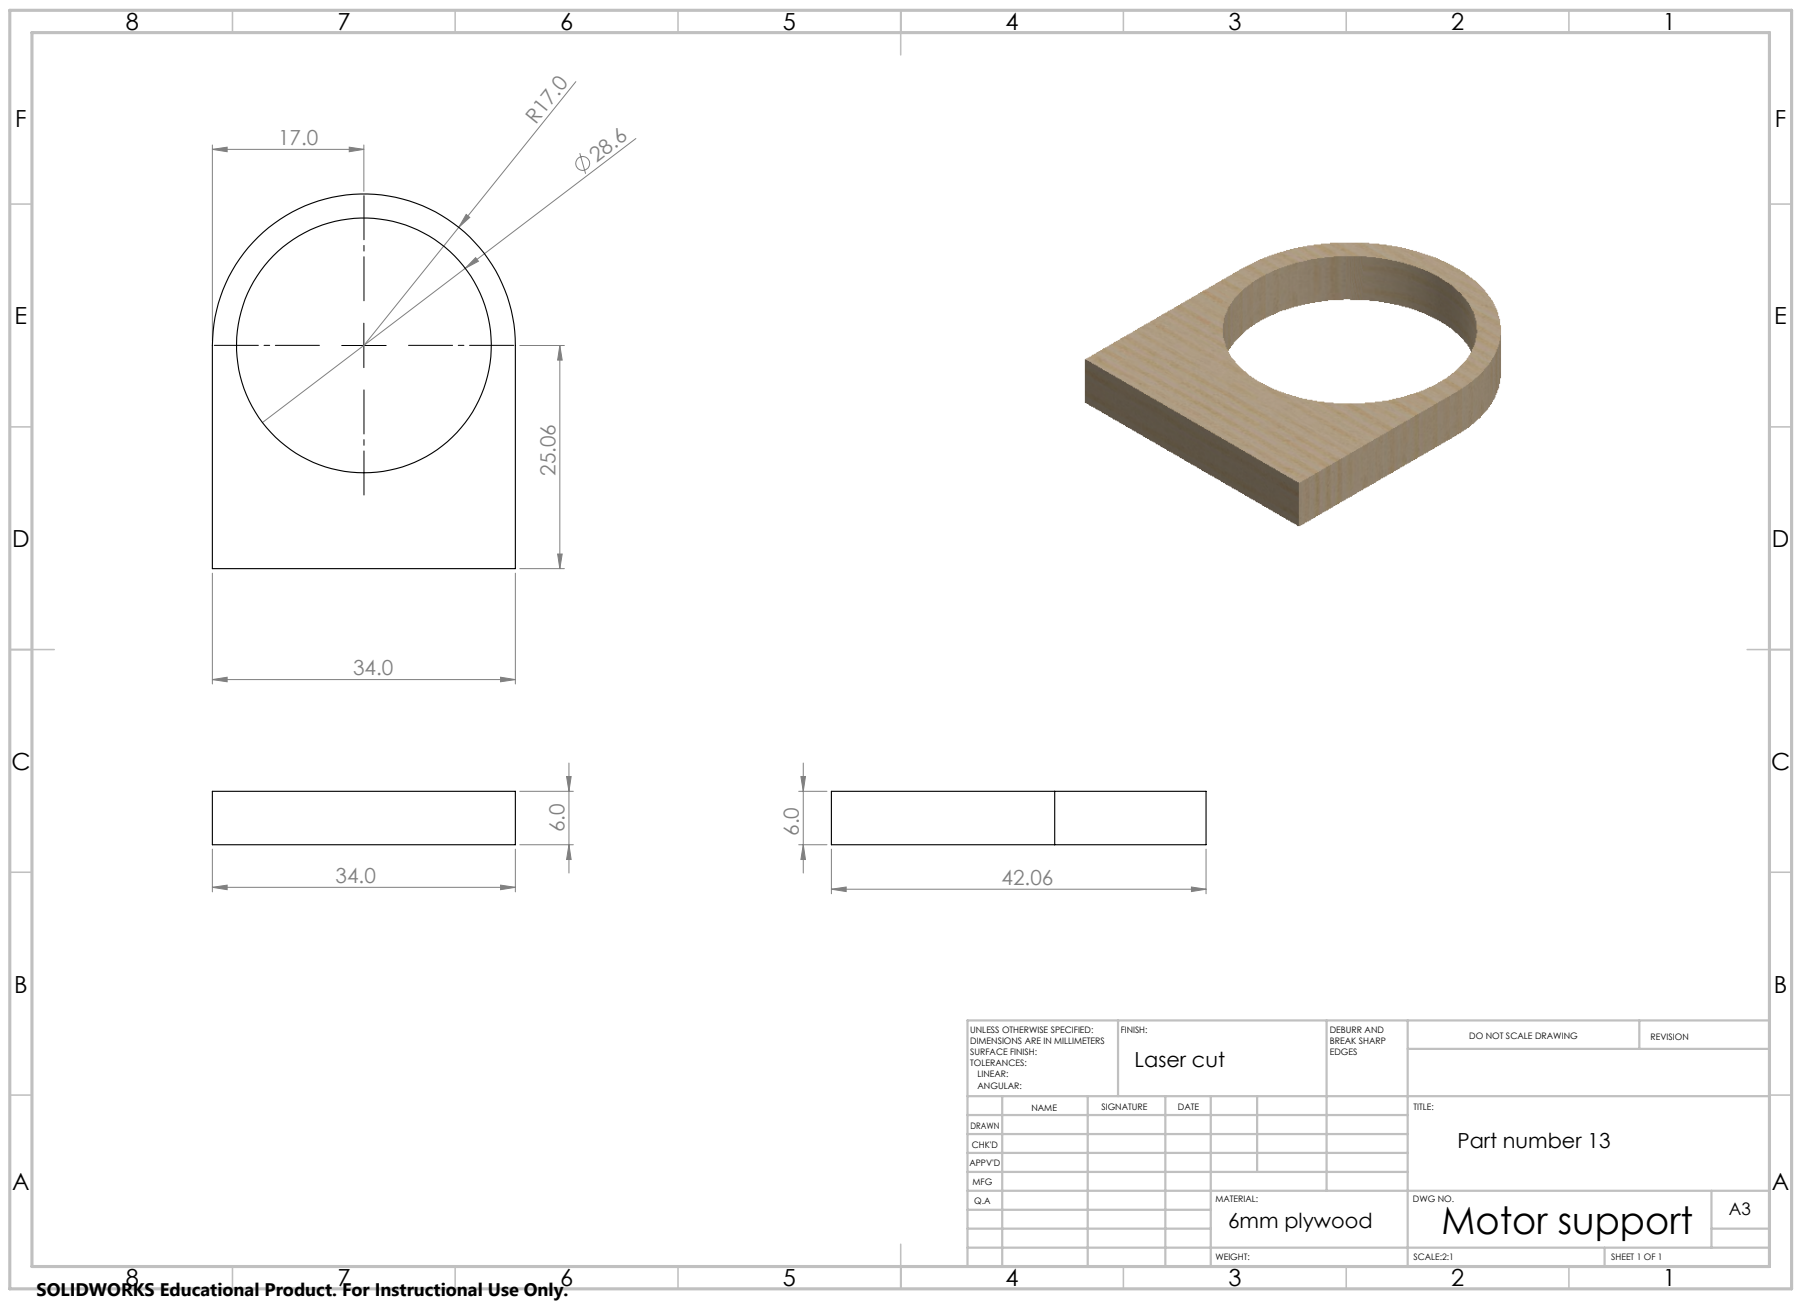
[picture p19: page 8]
Laser cut; FINISH:; DEBURR AND; BREAK SHARP; DO NOT SCALE DRAWING; REVISION

UNLESS OTHERWISE SPECIFIED:
DIMENSIONS ARE IN MILLIMETERS
SURFACE FINISH:
TOLERANCES:
LINEAR:
ANGULAR:

NAME | SIGNATURE | DATE | | | TITLE: Part number 13

DRAWN
CHK'D
APPV'D
MFG

Motor support

SCALE:2:1 | SHEET 1 OF 1

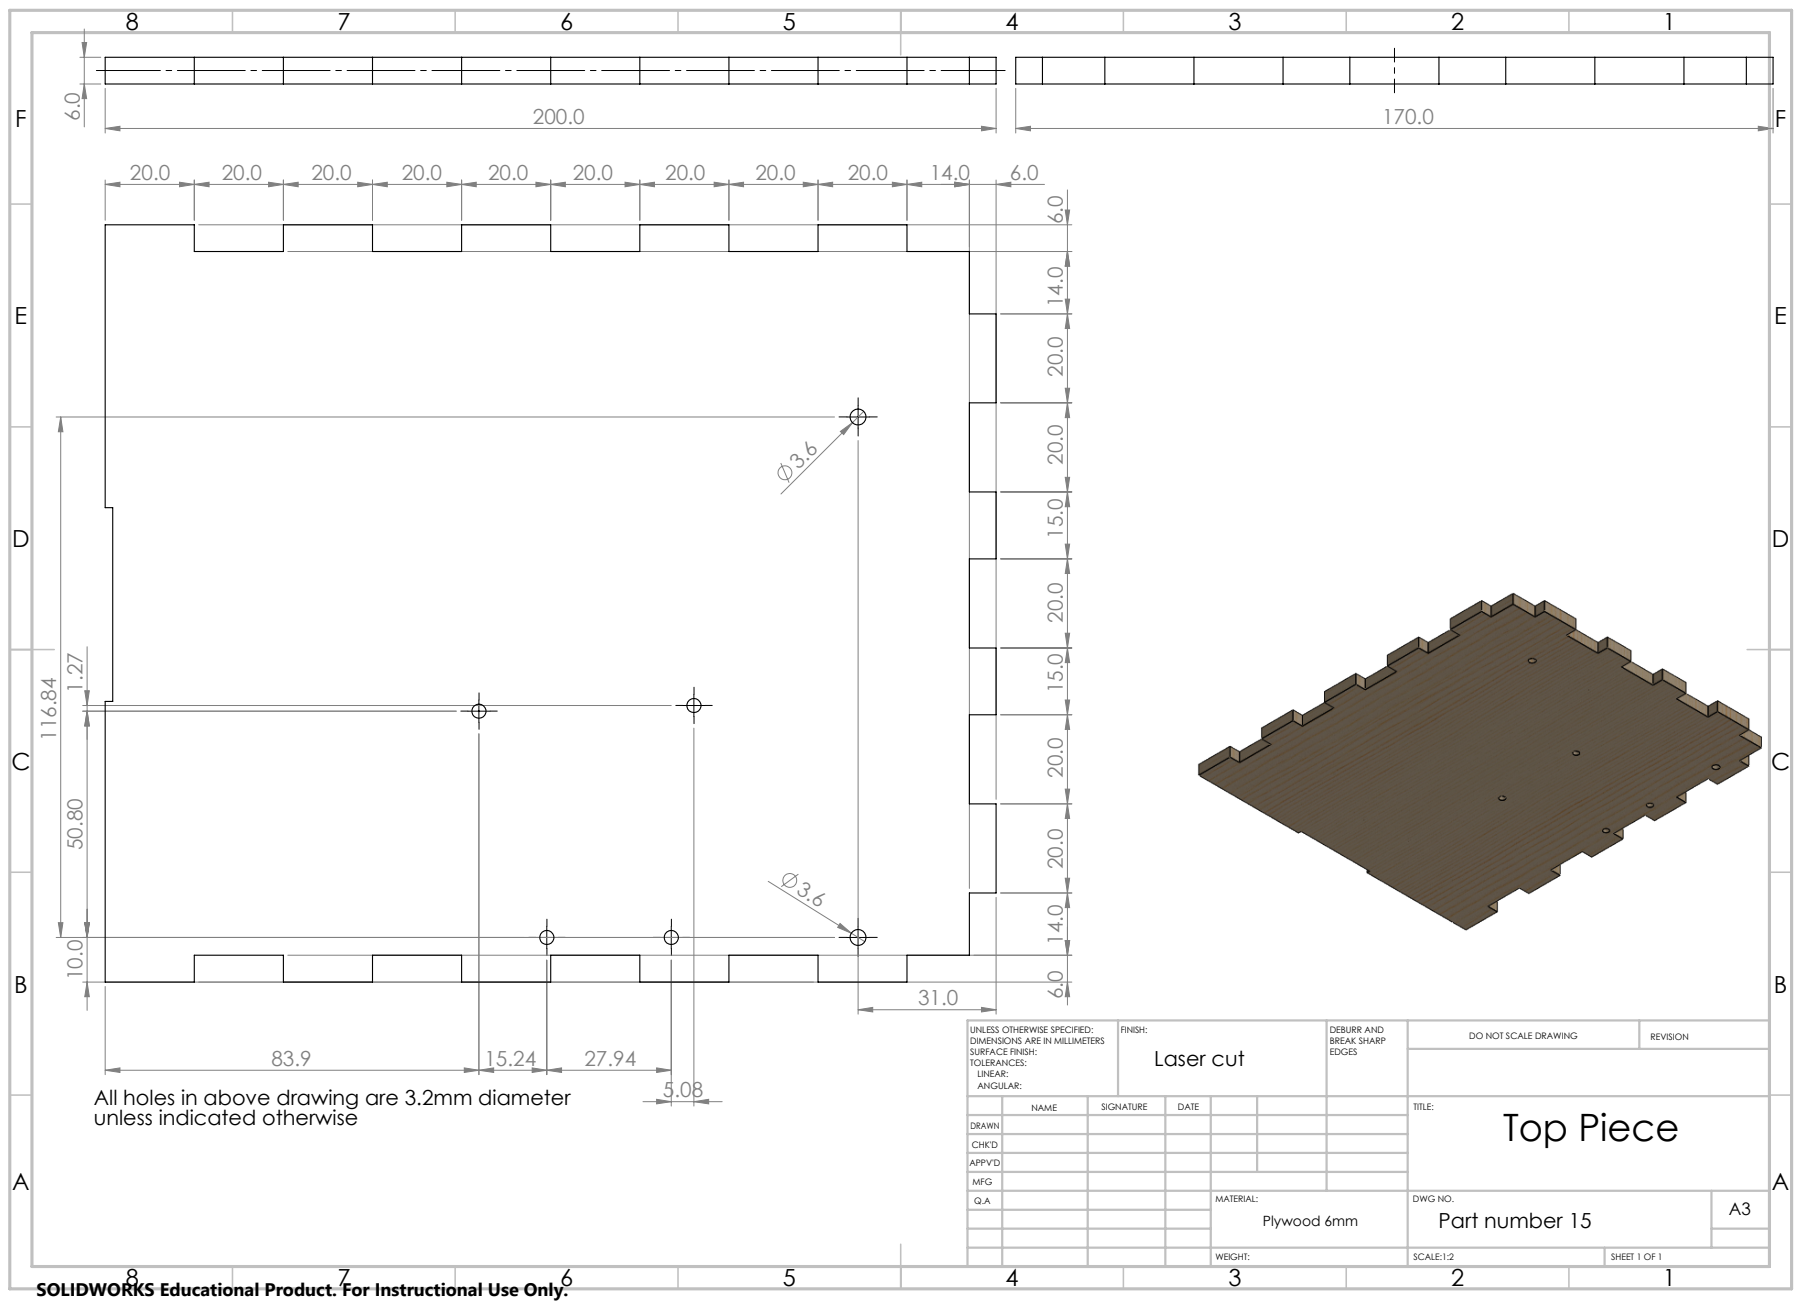
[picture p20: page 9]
Laser cut; FINISH:; DEBURR AND; BREAK SHARP; DO NOT SCALE DRAWING; REVISION
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

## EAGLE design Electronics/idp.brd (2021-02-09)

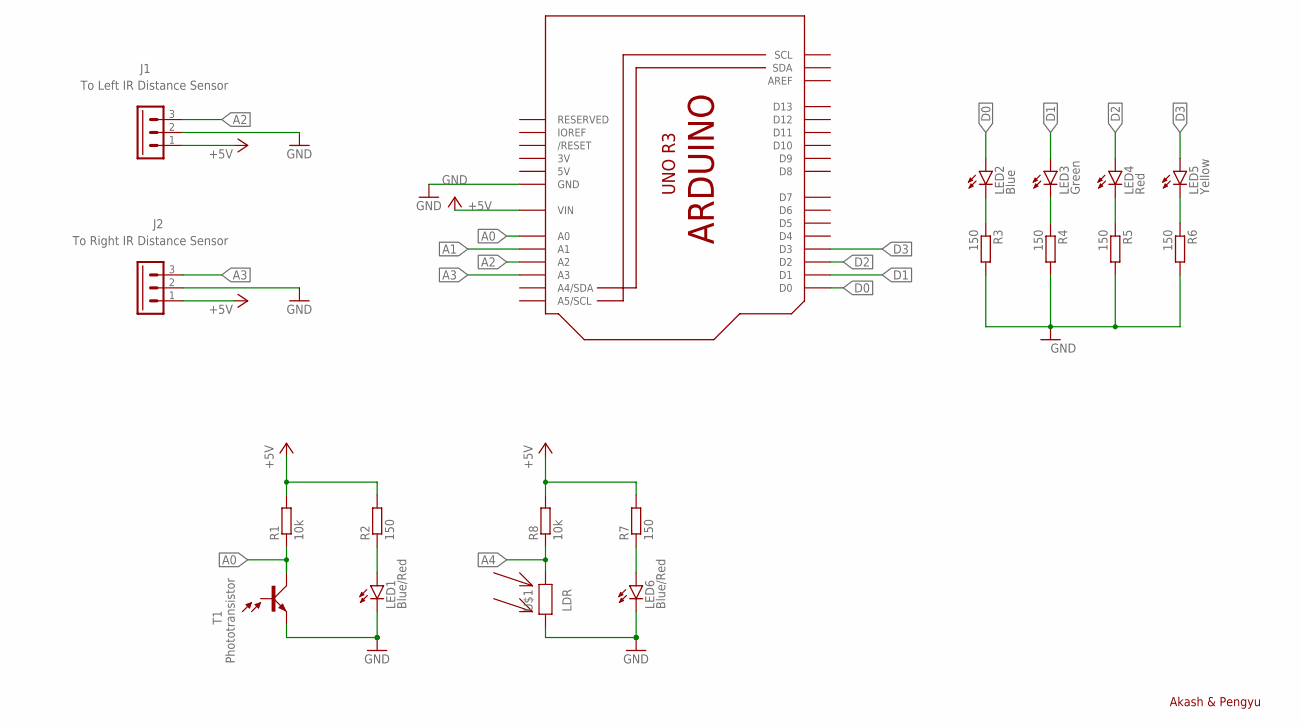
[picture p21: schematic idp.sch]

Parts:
J1: To Left IR Distance Sensor; 7395-03
J2: To Right IR Distance Sensor; 7395-03
LED1, LED6: Blue/Red; LED3MM
LED2: Blue; LED3MM
LED3: Green; LED3MM
LED4: Red; LED3MM
LED5: Yellow; LED3MM
M1: IDP_PROTOBOARD; IDP_PROTO
R1, R8: 10k; 0204/7
R2, R7: 150; 0204/7
R3, R4, R5, R6: 150; 0204V
T1: Phototransistor; SFH303
U$1: LDR

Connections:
3V: M1.3V
5V: M1.5V, M1.5V@0 (5V), M1.5V@1 (5V), M1.5V@2 (5V), M1.5V@3 (5V), M1.5V@4 (5V), M1.5V@5 (5V), M1.5V@6 (5V), M1.5V@7 (5V), M1.5V@8 (5V), M1.5V@9 (5V), M1.5V@10 (5V), M1.5V@11 (5V), M1.5V@12 (5V), M1.5V@13 (5V), M1.5V@14 (5V), M1.5V@15 (5V), M1.5V@16 (5V), M1.5V@17 (5V), M1.5V@18 (5V), M1.5V@19 (5V), M1.5V@20 (5V), M1.5V@21 (5V), M1.5V@22 (5V), M1.5V@23 (5V), M1.5V@24 (5V), M1.5V@25 (5V), M1.5V@26 (5V), M1.5V@27 (5V), M1.5V@28 (5V), M1.5V@29 (5V), M1.5V@30 (5V), M1.5V@31 (5V), M1.5V@32 (5V), M1.5V@33 (5V), M1.5V@34 (5V), M1.5V@35 (5V), M1.5V@36 (5V), M1.5V@37 (5V), M1.5V@38 (5V), M1.5V@39 (5V), M1.5V@40 (5V)
+5V: J1.1, J2.1, M1.VIN, R1.2, R2.2, R7.2, R8.2
A0: M1.A0, R1.1, T1.2 (C)
A1: M1.A1
A2: J1.3, M1.A2
A3: J2.3, M1.A3
A4: R8.1, U$1.P$2
D0: LED2.A, M1.D0
D1: LED3.A, M1.D1
D2: LED4.A, M1.D2
D3: LED5.A, M1.D3
GND: J1.2, J2.2, LED1.K (C), LED6.K (C), M1.GND, M1.GND16 (GND), M1.GND17 (GND), M1.GND18 (GND), M1.GND19 (GND), M1.GND20 (GND), M1.GND21 (GND), M1.GND22 (GND), M1.GND23 (GND), M1.GND24 (GND), M1.GND25 (GND), M1.GND@1 (GND), M1.GND@2 (GND), M1.GND@3 (GND), M1.GND@4 (GND), M1.GND@5 (GND), M1.GND@6 (GND), M1.GND@7 (GND), M1.GND@8 (GND), M1.GND@9 (GND), M1.GND@10 (GND), M1.GND@11 (GND), M1.GND@12 (GND), M1.GND@13 (GND), M1.GND@14 (GND), M1.GND@15 (GND), M1.GND@26 (GND), M1.GND@27 (GND), M1.GND@28 (GND), M1.GND@29 (GND), M1.GND@30 (GND), M1.GND@31 (GND), M1.GND@32 (GND), M1.GND@33 (GND), M1.GND@34 (GND), M1.GND@35 (GND), M1.GND@36 (GND), M1.GND@37 (GND), M1.GND@38 (GND), M1.GND@39 (GND), M1.GND@40 (GND), M1.GND@41 (GND), M1.GND@42 (GND), M1.GND@43 (GND), M1.GND@44 (GND), M1.GND@45 (GND), M1.GND@46 (GND), M1.GND@47 (GND), M1.GND@48 (GND), R3.2, R4.2, R5.2, R6.2, T1.1 (E), U$1.P$1
unnamed: LED2.K (C), R3.1
unnamed: LED6.A, R7.1
unnamed: LED1.A, R2.1
unnamed: LED3.K (C), R4.1
unnamed: LED4.K (C), R5.1
unnamed: LED5.K (C), R6.1

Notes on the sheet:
Akash & Pengyu

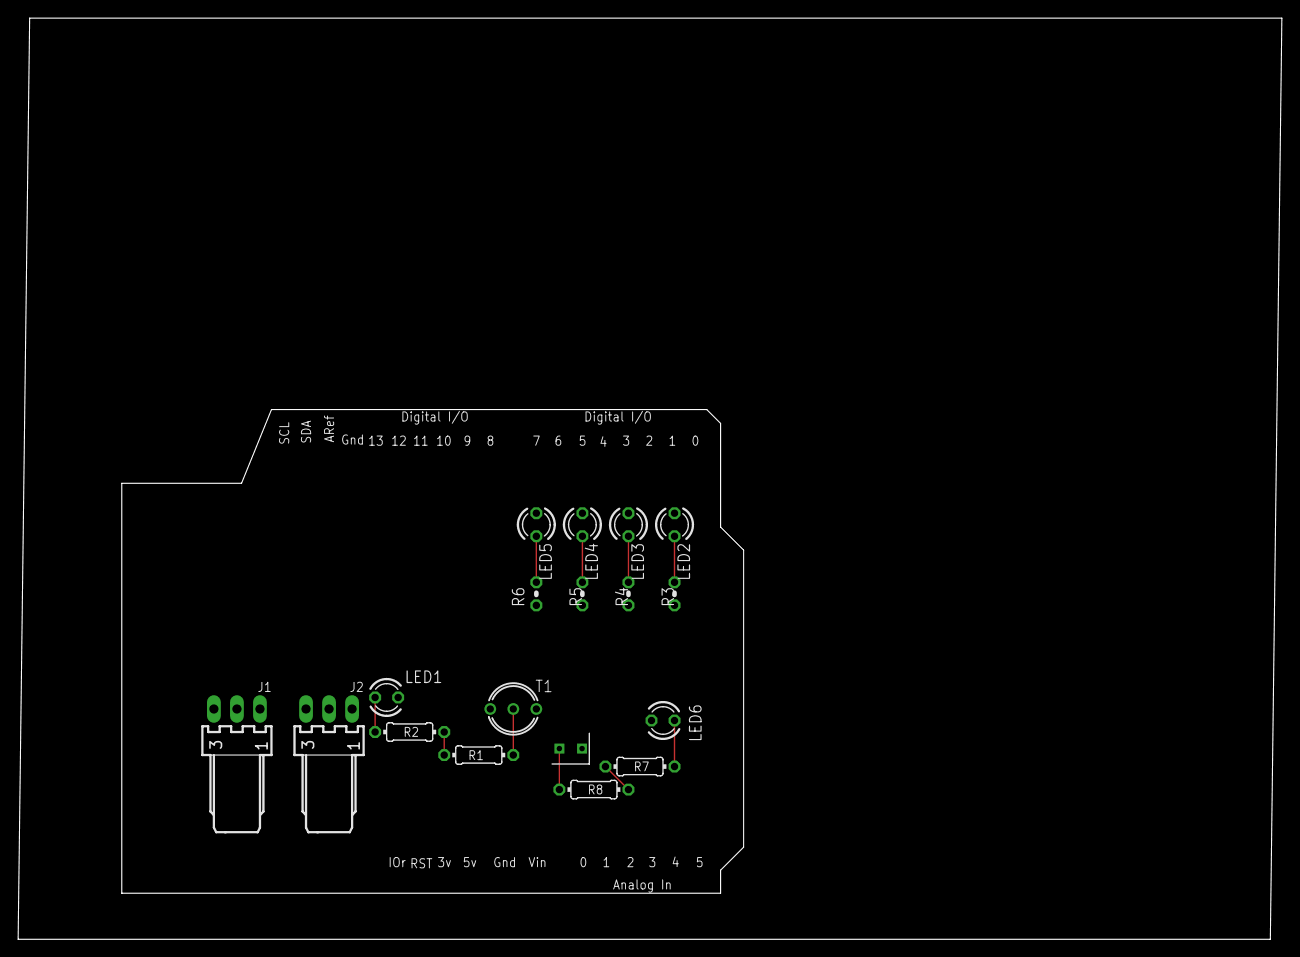
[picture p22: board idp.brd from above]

Board: 2 copper layers, 139.4 x 101.6 mm, 19 parts (0 on the bottom side), 17 nets.

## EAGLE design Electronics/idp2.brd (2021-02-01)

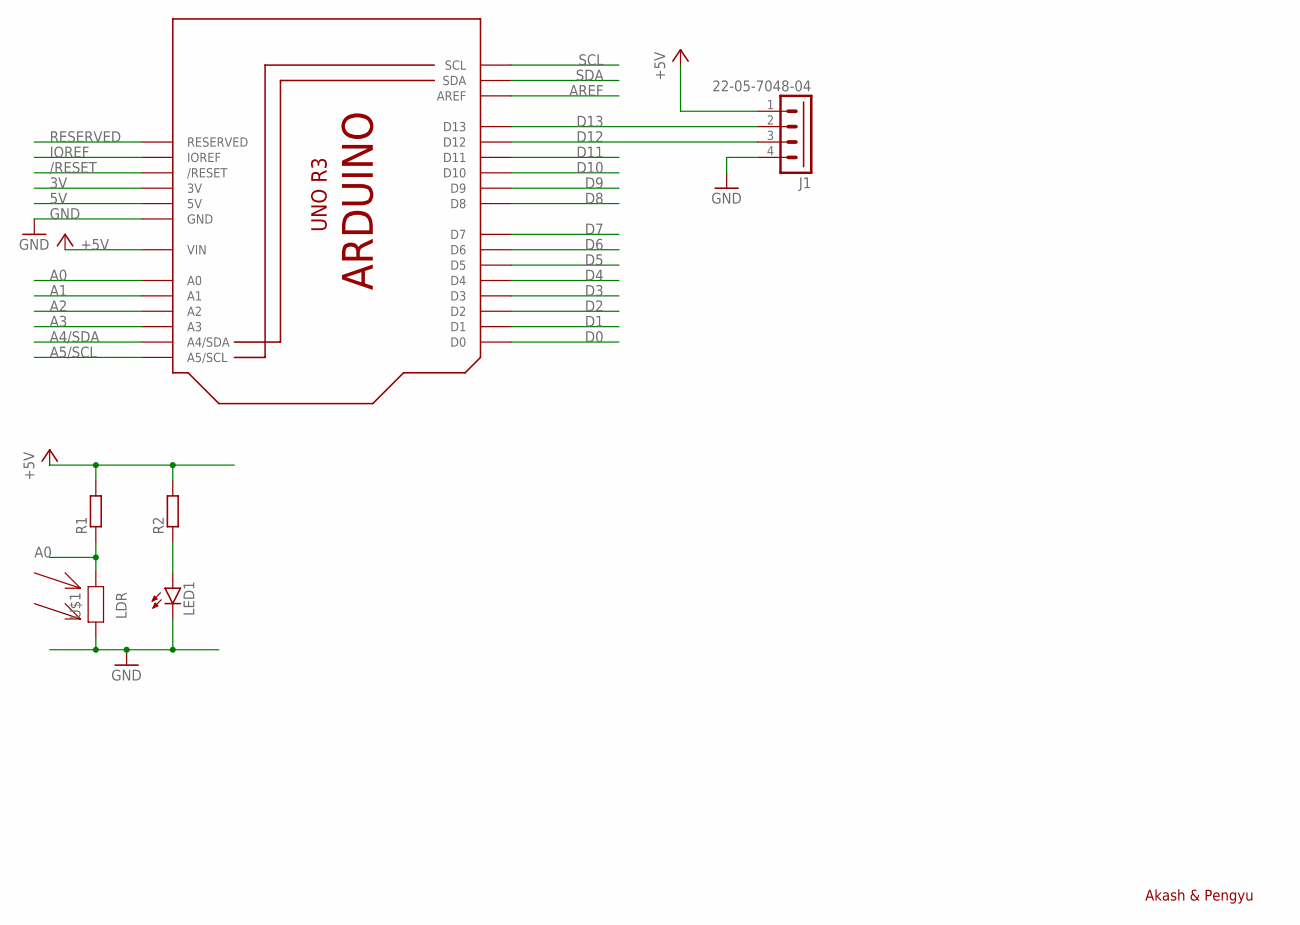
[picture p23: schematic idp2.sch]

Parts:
J1: 22-05-7048-04; 7395-04
LED1: LED_25MM; LED5MM
M1: IDP_PROTOBOARD; IDP_PROTO
R1, R2: R-EU_0207/5V; 0207/5V
U$1: LDR

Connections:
3V: M1.3V
5V: M1.5V, M1.5V@0 (5V), M1.5V@1 (5V), M1.5V@2 (5V), M1.5V@3 (5V), M1.5V@4 (5V), M1.5V@5 (5V), M1.5V@6 (5V), M1.5V@7 (5V), M1.5V@8 (5V), M1.5V@9 (5V), M1.5V@10 (5V), M1.5V@11 (5V), M1.5V@12 (5V), M1.5V@13 (5V), M1.5V@14 (5V), M1.5V@15 (5V), M1.5V@16 (5V), M1.5V@17 (5V), M1.5V@18 (5V), M1.5V@19 (5V), M1.5V@20 (5V), M1.5V@21 (5V), M1.5V@22 (5V), M1.5V@23 (5V), M1.5V@24 (5V), M1.5V@25 (5V), M1.5V@26 (5V), M1.5V@27 (5V), M1.5V@28 (5V), M1.5V@29 (5V), M1.5V@30 (5V), M1.5V@31 (5V), M1.5V@32 (5V), M1.5V@33 (5V), M1.5V@34 (5V), M1.5V@35 (5V), M1.5V@36 (5V), M1.5V@37 (5V), M1.5V@38 (5V), M1.5V@39 (5V), M1.5V@40 (5V)
+5V: J1.1, M1.VIN, R1.2, R2.2
/RESET: M1.RESET (/RESET)
A0: M1.A0, R1.1, U$1.P$2
A1: M1.A1
A2: M1.A2
A3: M1.A3
A4/SDA: M1.A4 (A4/SDA)
A5/SCL: M1.A5 (A5/SCL)
AREF: M1.AREF
D0: M1.D0
D1: M1.D1
D2: M1.D2
D3: M1.D3
D4: M1.D4
D5: M1.D5
D6: M1.D6
D7: M1.D7
D8: M1.D8
D9: M1.D9
D10: M1.D10
D11: M1.D11
D12: J1.3, M1.D12
D13: J1.2, M1.D13
GND: J1.4, LED1.K (C), M1.GND, M1.GND16 (GND), M1.GND17 (GND), M1.GND18 (GND), M1.GND19 (GND), M1.GND20 (GND), M1.GND21 (GND), M1.GND22 (GND), M1.GND23 (GND), M1.GND24 (GND), M1.GND25 (GND), M1.GND@1 (GND), M1.GND@2 (GND), M1.GND@3 (GND), M1.GND@4 (GND), M1.GND@5 (GND), M1.GND@6 (GND), M1.GND@7 (GND), M1.GND@8 (GND), M1.GND@9 (GND), M1.GND@10 (GND), M1.GND@11 (GND), M1.GND@12 (GND), M1.GND@13 (GND), M1.GND@14 (GND), M1.GND@15 (GND), M1.GND@26 (GND), M1.GND@27 (GND), M1.GND@28 (GND), M1.GND@29 (GND), M1.GND@30 (GND), M1.GND@31 (GND), M1.GND@32 (GND), M1.GND@33 (GND), M1.GND@34 (GND), M1.GND@35 (GND), M1.GND@36 (GND), M1.GND@37 (GND), M1.GND@38 (GND), M1.GND@39 (GND), M1.GND@40 (GND), M1.GND@41 (GND), M1.GND@42 (GND), M1.GND@43 (GND), M1.GND@44 (GND), M1.GND@45 (GND), M1.GND@46 (GND), M1.GND@47 (GND), M1.GND@48 (GND), U$1.P$1
IOREF: M1.IOREF
unnamed: LED1.A, R2.1
RESERVED: M1.RESERVED
SCL: M1.SCL
SDA: M1.SDA

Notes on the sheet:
Akash & Pengyu

Board: 2 copper layers, 6 parts (0 on the bottom side), 7 nets, no tracks yet.

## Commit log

2021-01-30 Added schematics
    [idp.brd, idp.sch]
2021-02-01 With distance sensor
    [idp2.brd, idp2.sch]
2021-02-02 Updated eagle schematics
    [idp.brd, idp.sch]
2021-02-04 Schematics change
    [idp.brd, idp.sch]
2021-02-05 fixed bearing issues with gp controller
2021-02-05 commented out print values which he used for tests
2021-02-06 added camera and changed dimensions of wbts robot
2021-02-06 Added rotating servo motor with distance sensor
2021-02-06 fixed rotation axis of servo motor
2021-02-06 Changed anchor for wheels
2021-02-07 updated schematics
    [idp.brd, idp.sch]
2021-02-07 led indicators added
2021-02-08 Schematics changed
    [idp.sch]
2021-02-08 PCB board
    [idp.brd]
2021-02-09 added LDR. created board
    [idp.brd, idp.sch]
2021-02-09 north aligned with +ve x-axis.
2021-02-09 shifted ds sensor down
2021-02-09 modified robocar. added camera controller
2021-02-11 commented out print statements
2021-02-15 added leds to webots robot and removed servo motor
2021-02-17 removed print statements. Don't store blocks in a file. updated list of colours
2021-02-17 cleaned up print statements
2021-02-17 bottom distance sensor limitted to 1.4 m
2021-02-17 reduced range of ds sensors
2021-02-17 print block colour in colorama
2021-02-17 made some changes to the block detection and sensor noise
